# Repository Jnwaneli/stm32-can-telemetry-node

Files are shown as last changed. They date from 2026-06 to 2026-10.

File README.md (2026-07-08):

# STM32 CAN Telemetry Node - Rev A

## Overview

The STM32 CAN Telemetry Node is a custom STM32-based telemetry PCB designed in Altium Designer. The board is intended to collect analog, digital, and frequency-based sensor inputs and transmit telemetry data over a CAN bus.

Rev A includes protected 12 V input power, +5 V and +3.3 V regulation, an STM32F103C8T6 microcontroller, CAN transceiver interface, sensor input conditioning, SWD programming access, debug LEDs, test points, and mounting holes.

The hardware design is complete, routed, DRC-clean, and prepared for manufacturing. The repository also includes a starter STM32CubeMX / STM32CubeIDE firmware framework, CAN message map, bring-up documentation, and complete manufacturing outputs.

## Board Preview

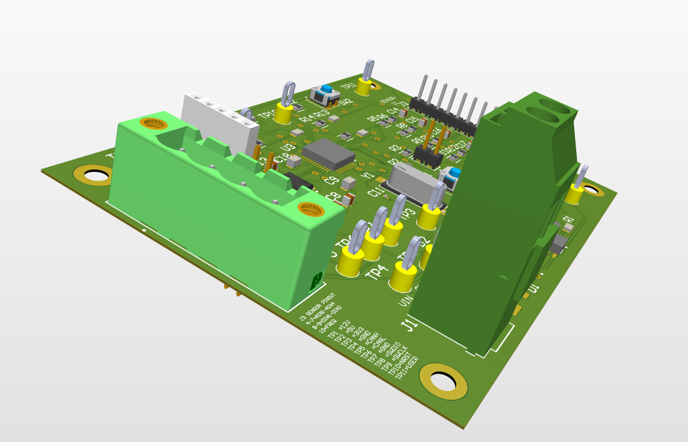
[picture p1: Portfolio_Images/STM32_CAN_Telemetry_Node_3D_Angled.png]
STM32 CAN Telemetry PCB 3D Render


**Figure 1.** 3D angled render of the STM32 CAN Telemetry Node Rev A PCB.

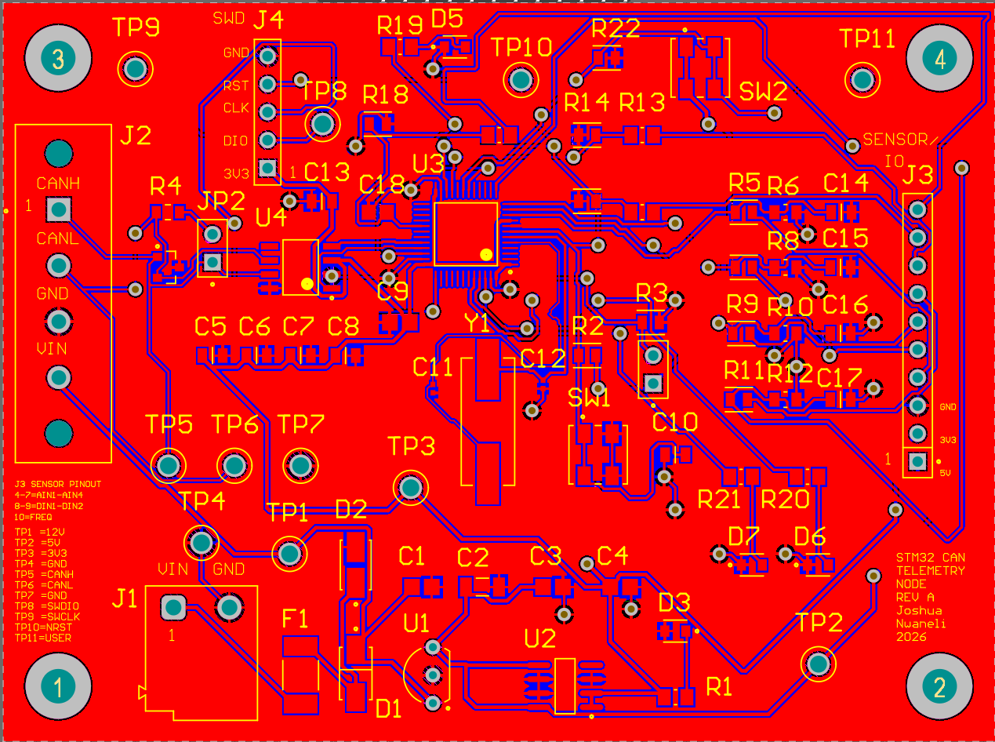
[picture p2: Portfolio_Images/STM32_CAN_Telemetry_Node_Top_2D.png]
STM32 CAN Telemetry PCB Top View


**Figure 2.** Top-side PCB layout view showing component placement, routing, connectors, mounting holes, and board labeling.

## Engineering Highlights

- Designed a custom STM32F103-based CAN telemetry PCB for vehicle sensor acquisition.
- Implemented protected 12 V input, +5 V/+3.3 V regulation, sensor inputs, CAN transceiver interface, SWD access, LEDs, and test points.
- Routed a 90 mm x 67 mm PCB and passed Altium DRC with 0 warnings, 0 rule violations, and 0 unrouted nets.
- Generated manufacturing outputs including BOM, Gerbers, drill files, pick-and-place files, and DRC report.
- Created STM32CubeMX/CubeIDE starter firmware for ADC sampling, CAN payload packing, and 100 ms CAN transmit-loop structure.

## What to Look At

- `Portfolio_Images/` - PCB renders, DRC result, STM32CubeMX configuration, and STM32CubeIDE build screenshot.
- `Manufacturing/` - Gerbers, drill files, BOM, pick-and-place files, and DRC report.
- `Docs/Design_Report.pdf` - Full hardware design explanation and design decisions.
- `Docs/CAN_Message_Map.xlsx` - Planned CAN frame structure and signal map.
- `Firmware/` - STM32CubeMX / STM32CubeIDE starter firmware.

## Project Status

- Schematic complete
- PCB layout routed
- Ground pours completed
- DRC passed with 0 warnings, 0 rule violations, and 0 unrouted nets
- Manufacturing outputs generated
- STM32CubeMX / STM32CubeIDE starter firmware created
- Firmware builds with 0 errors

## DRC Result

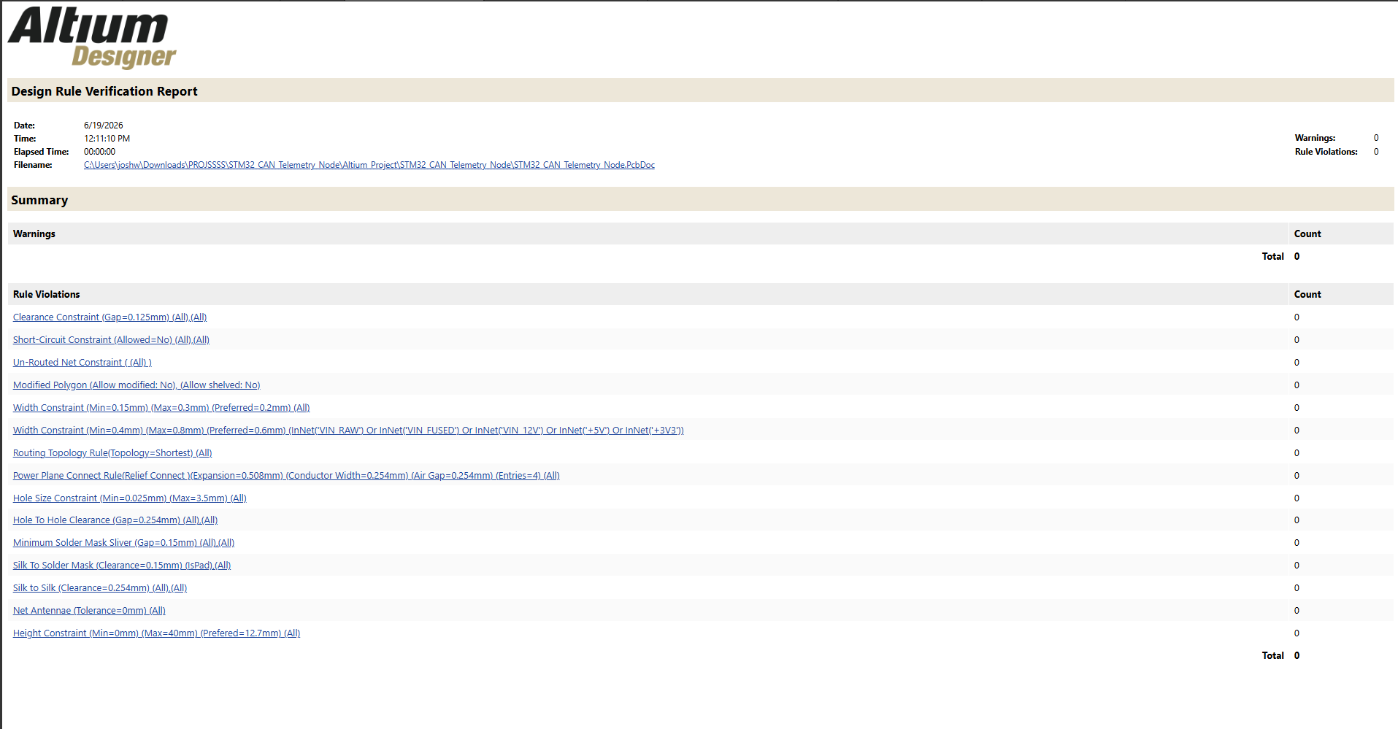
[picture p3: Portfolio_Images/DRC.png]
DRC Report


**Figure 3.** Altium Designer DRC result showing 0 warnings, 0 rule violations, and 0 unrouted nets.

## Key Features

- STM32F103C8T6 microcontroller, LQFP-48
- 12 V input through protected power path
- +5 V and +3.3 V power rails
- SN65HVD230-style 3.3 V CAN transceiver interface
- CANH/CANL connector
- Optional 120 ohm CAN termination jumper
- Four analog inputs with divider/filter networks
- Two digital inputs with pull-down networks
- One frequency/wheel-speed input
- SWD programming/debug header
- Reset and BOOT0 circuitry
- Status, CAN activity, and error LEDs
- User button
- Test points for power, CAN, SWD, reset, and user input
- 90 mm x 67 mm PCB

## System Architecture

```text
12 V Input
  -> Fuse / Protection
  -> 5 V Regulator
  -> 3.3 V Regulator
  -> STM32F103C8T6
  -> CAN Transceiver
  -> CANH / CANL Connector
```

Additional inputs:

```text
Analog Sensors -> Divider/Filter -> STM32 ADC
Digital Inputs -> Pull-down/Series Resistor -> STM32 GPIO
Frequency Input -> Filter/Pull-down -> STM32 Timer Input
SWD Header -> STM32 Programming/Debug
LEDs/Button -> Firmware Bring-up and Debug
```

## Planned CAN Message

| CAN ID | DLC | Bytes | Signal | Description |
|---|---:|---|---|---|
| 0x100 | 8 | Byte 0-1 | AIN1_RAW | Raw ADC value from AIN1 |
| 0x100 | 8 | Byte 2-3 | AIN2_RAW | Raw ADC value from AIN2 |
| 0x100 | 8 | Byte 4-5 | AIN3_RAW | Raw ADC value from AIN3 |
| 0x100 | 8 | Byte 6-7 | AIN4_RAW | Raw ADC value from AIN4 |

Planned CAN bitrate: 500 kbps  
Planned transmit period: 100 ms

## Firmware Status

A starter STM32CubeMX / STM32CubeIDE firmware framework has been added for ADC-to-CAN telemetry bring-up. The firmware configures GPIO, ADC, CAN message packing, and a 100 ms transmit loop for CAN ID `0x100`.

Current firmware status:

- STM32CubeMX configuration created for STM32F103C8T6 / STM32F103C8Tx
- SWD debug enabled
- HSE configured for the external 8 MHz crystal
- ADC1 configured for PA0-PA3 analog inputs
- CAN configured on PA11 / PA12 for planned 500 kbps operation
- CAN payload structure matches the project message map
- Starter firmware builds with 0 errors

## Firmware Configuration and Build

The starter firmware was configured in STM32CubeMX and generated for STM32CubeIDE. The project currently builds with 0 errors.

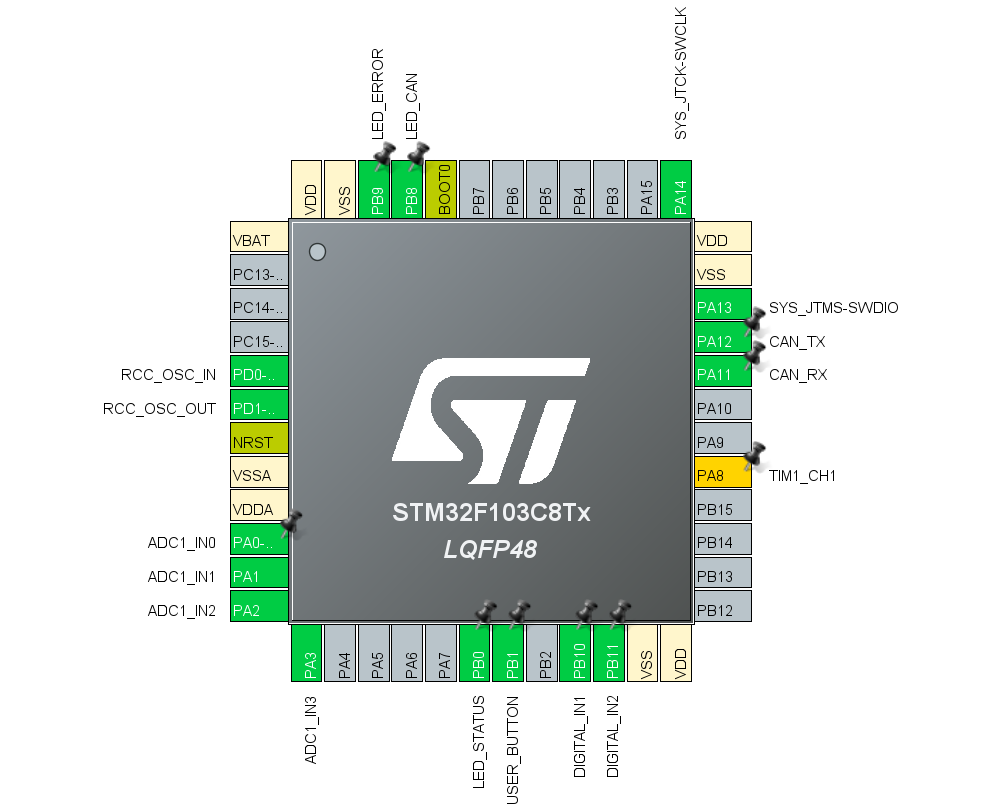
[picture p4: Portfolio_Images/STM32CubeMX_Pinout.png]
STM32CubeMX Pinout


**Figure 4.** STM32CubeMX pinout configuration showing ADC inputs, CAN pins, SWD debug pins, HSE crystal pins, GPIO LEDs, and user input signals.

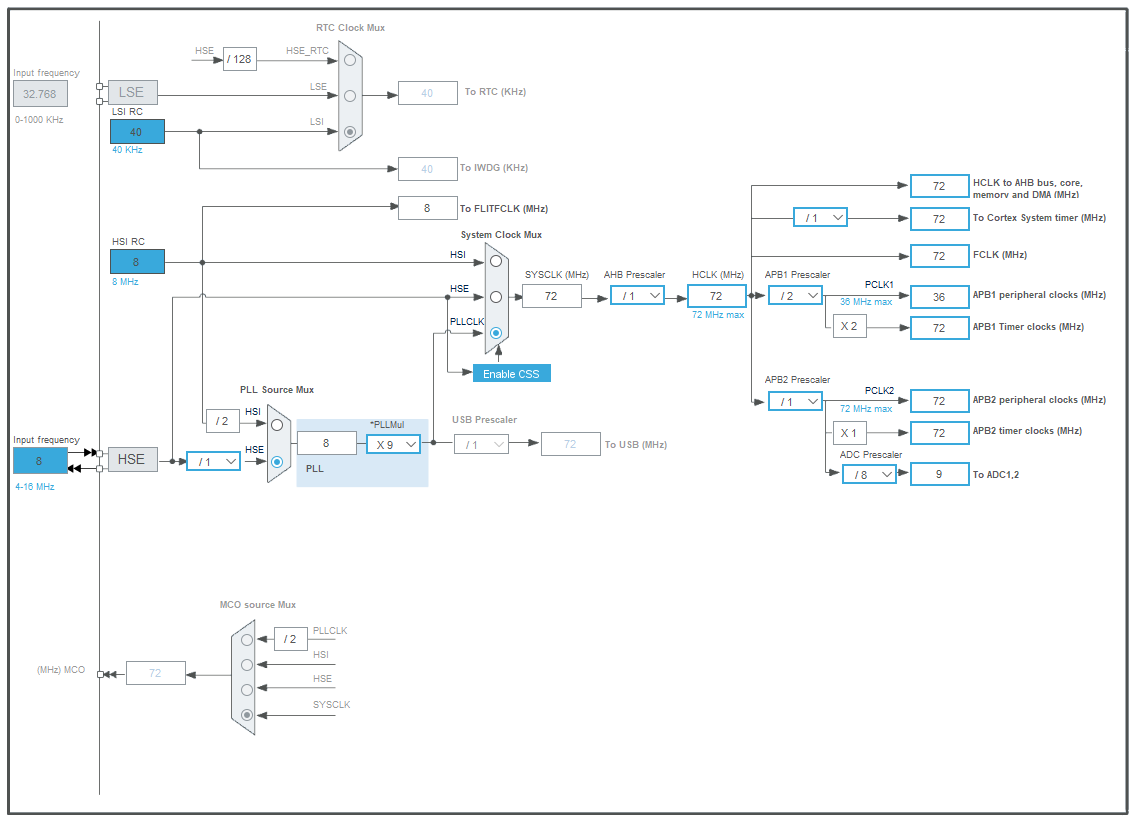
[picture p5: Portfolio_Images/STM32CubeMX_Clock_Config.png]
STM32CubeMX Clock Configuration


**Figure 5.** STM32CubeMX clock configuration using the external 8 MHz HSE crystal with PLL configuration for the STM32F103 system clock.

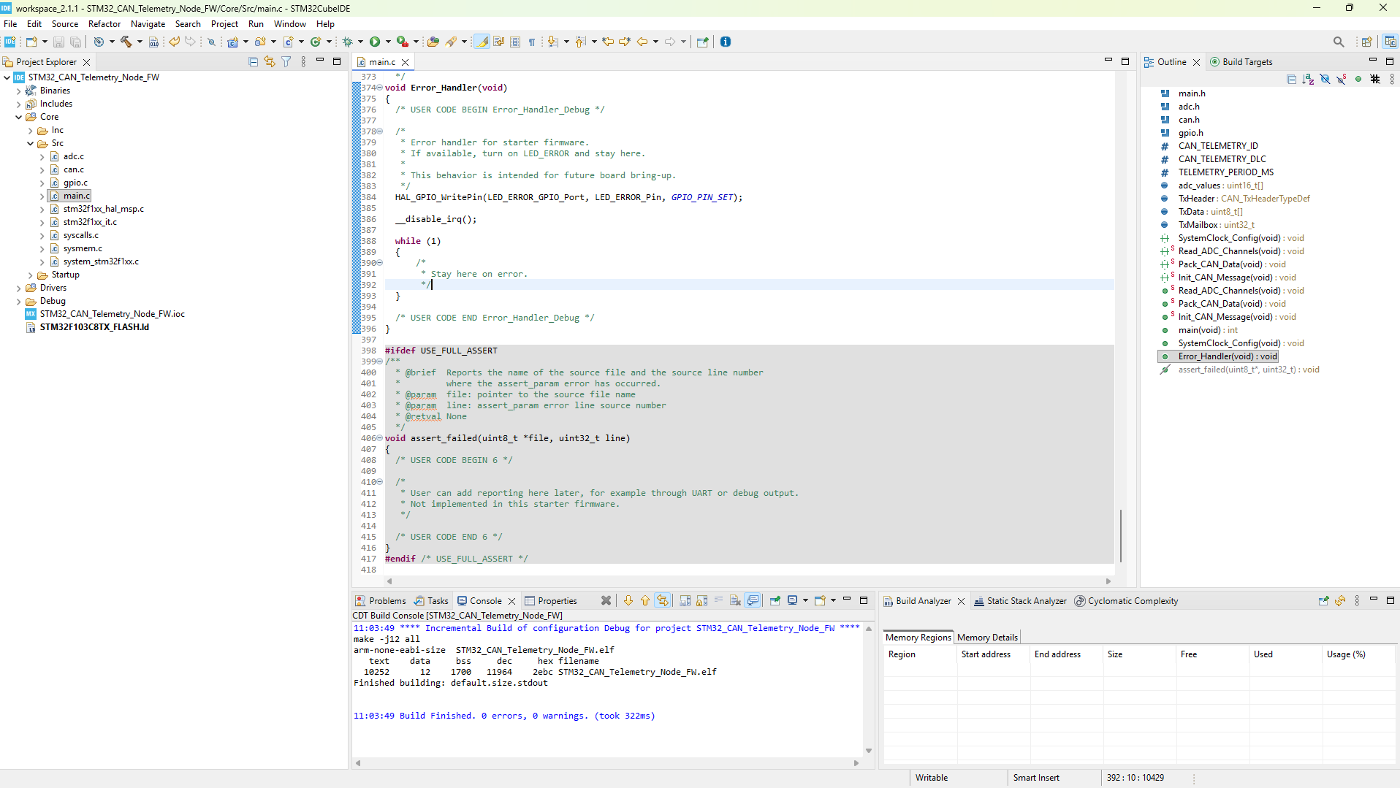
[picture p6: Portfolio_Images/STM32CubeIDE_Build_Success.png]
STM32CubeIDE Build Success


**Figure 6.** STM32CubeIDE build output showing the starter firmware project building with 0 errors.

## Project Structure

```text
STM32_CAN_Telemetry_Node/
├── Altium_Project/
├── Manufacturing/
│   ├── Gerbers/
│   ├── NC_Drill/
│   ├── BOM/
│   ├── PickPlace/
│   └── DRC/
├── Docs/
│   ├── Design_Report.pdf
│   ├── Bringup_Test_Plan.pdf
│   ├── CAN_Message_Map.xlsx
│   └── Firmware_Starter_Plan.pdf
├── Portfolio_Images/
│   ├── STM32_CAN_Telemetry_Node_3D_Angled.png
│   ├── STM32_CAN_Telemetry_Node_Top_2D.png
│   ├── DRC.png
│   ├── STM32CubeMX_Pinout.png
│   ├── STM32CubeMX_Clock_Config.png
│   └── STM32CubeIDE_Build_Success.png
├── Firmware/
│   ├── README.md
│   └── STM32_CAN_Telemetry_Node_FW/
└── README.md
```

## Documentation

Main documentation files:

- `Design_Report.pdf` - Full hardware design report
- `Bringup_Test_Plan.pdf` - Step-by-step hardware bring-up checklist
- `CAN_Message_Map.xlsx` - CAN frame and signal map
- `Firmware_Starter_Plan.pdf` - STM32 firmware bring-up approach

## Starter Firmware Main Loop

The starter firmware reads AIN1-AIN4, packs the raw ADC values into CAN frame ID `0x100`, and transmits the frame every 100 ms. Debug LEDs are included for heartbeat, CAN activity, and error indication.

Basic starter loop:

```c
while (1)
{
    Read_ADC_Channels();
    Pack_CAN_Data();

    HAL_CAN_AddTxMessage(&hcan, &TxHeader, TxData, &TxMailbox);

    HAL_GPIO_TogglePin(LED_STATUS_GPIO_Port, LED_STATUS_Pin);
    HAL_Delay(100);
}
```

## Design Scope

Rev A focuses on the core telemetry-node design package:

- Protected power input and regulated 5 V / 3.3 V rails
- STM32F103 support circuitry and SWD programming access
- ADC-based analog sensor input interfaces
- Digital and frequency input interfaces
- CAN transceiver interface and CANH/CANL connector
- Debug LEDs, user input, test points, and mounting features
- Manufacturing outputs and design documentation

## Future Rev B Improvements

- Improved automotive-grade input protection
- USB-C programming/debugging option
- SD card logging
- Enclosure or mounting bracket
- Optional second CAN channel
- More compact layout after Rev A review

## Author

Joshua Nwaneli  
June 2026

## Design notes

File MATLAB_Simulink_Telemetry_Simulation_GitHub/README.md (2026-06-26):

# MATLAB/Simulink Sensor Filtering and CAN Telemetry Simulation

## Overview

This project supports the STM32 CAN Telemetry Node Rev A by modeling the planned analog telemetry signal path before physical hardware bring-up.

The project combines a MATLAB simulation and a Simulink signal-flow model to show how four analog sensor inputs can be scaled, converted into STM32 ADC counts, filtered, and prepared for the planned CAN telemetry frame.

```text
Analog sensor input
  -> resistor-divider scaling
  -> STM32 ADC raw count
  -> filtering / signal conditioning
  -> CAN payload formatting
  -> CAN ID 0x100 telemetry frame
```

This project is part of the larger STM32 CAN Telemetry Node Rev A portfolio project.

## Project Status

This is a simulation and documentation project. It does not claim physical PCB, ADC, or CAN bus validation.

The Rev A PCB has not yet been physically assembled or tested, so these files are intended to support planned firmware bring-up and telemetry validation.

## Folder Structure

```text
MATLAB_Simulink_Telemetry_Simulation/
├── README.md
├── MATLAB/
│   └── adc_can_telemetry_simulation.m
├── Simulink/
│   ├── create_stm32_can_telemetry_model.m
│   └── stm32_can_telemetry_filter_model.slx
├── plots/
│   ├── raw_adc_counts.png
│   ├── estimated_sensor_voltages.png
│   ├── filtered_sensor_voltages.png
│   ├── example_can_payload_bytes.png
│   └── telemetry_simulation_output.csv
├── images/
│   ├── simulink_model_overview.png
│   ├── raw_adc_counts_scope.png
│   └── filtered_adc_counts_scope.png
└── docs/
    └── MATLAB_Simulink_Telemetry_Simulation_Report.pdf
```

## MATLAB Simulation

The MATLAB script is located at:

```text
MATLAB/adc_can_telemetry_simulation.m
```

It performs:

- Synthetic sensor-signal generation for four analog telemetry inputs
- STM32 12-bit ADC scaling using a 3.3 V reference
- Rev A resistor-divider modeling using 10 kOhm / 20 kOhm values
- Sensor-side voltage estimation from ADC counts
- Moving-average filtering
- CAN payload packing for standard ID `0x100`
- Plot and CSV generation

Run in MATLAB:

```matlab
cd MATLAB
adc_can_telemetry_simulation
```

Generated outputs are saved to the `plots/` folder.

## MATLAB Results

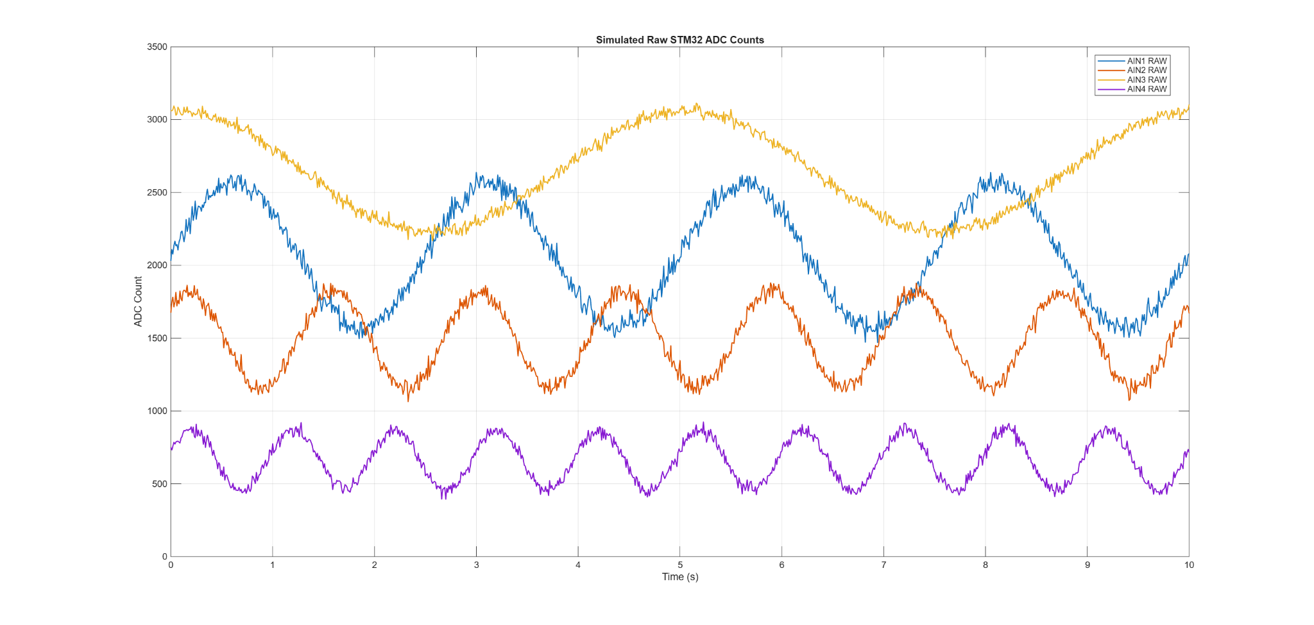
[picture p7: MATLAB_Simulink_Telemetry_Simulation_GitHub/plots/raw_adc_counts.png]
Simulated Raw STM32 ADC Counts


**Figure 1.** Simulated raw STM32 ADC counts for four analog telemetry channels.

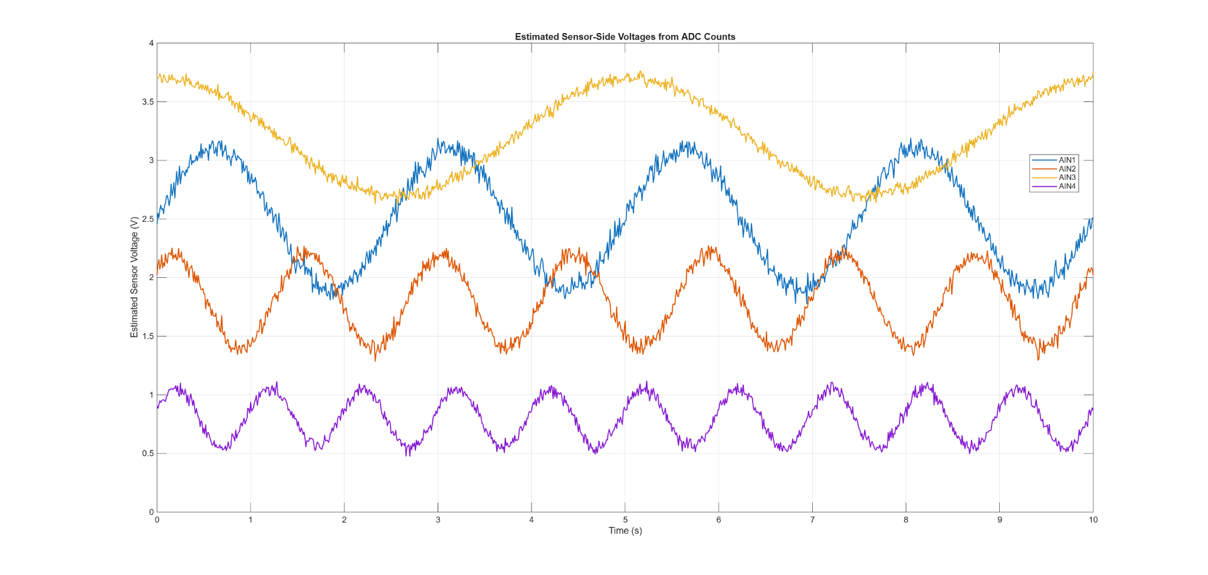
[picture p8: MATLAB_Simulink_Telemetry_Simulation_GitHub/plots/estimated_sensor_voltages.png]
Estimated Sensor-Side Voltages


**Figure 2.** Estimated sensor-side voltages reconstructed from ADC counts using the Rev A resistor-divider model.

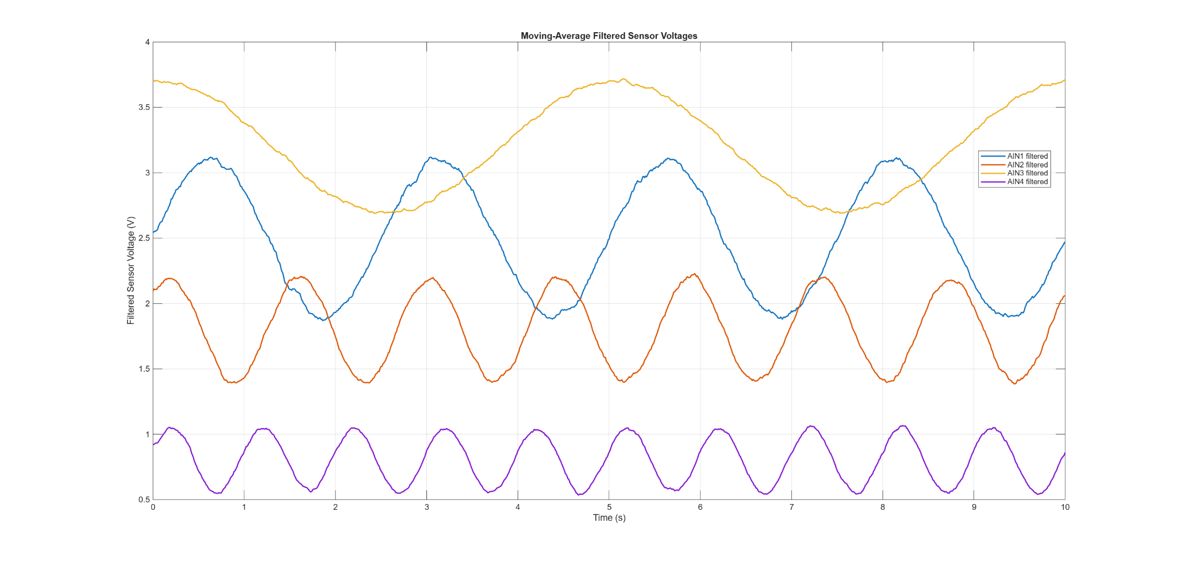
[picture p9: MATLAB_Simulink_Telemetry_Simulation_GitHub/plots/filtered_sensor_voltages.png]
Moving-Average Filtered Sensor Voltages


**Figure 3.** Moving-average filtered sensor voltage estimates for AIN1-AIN4.

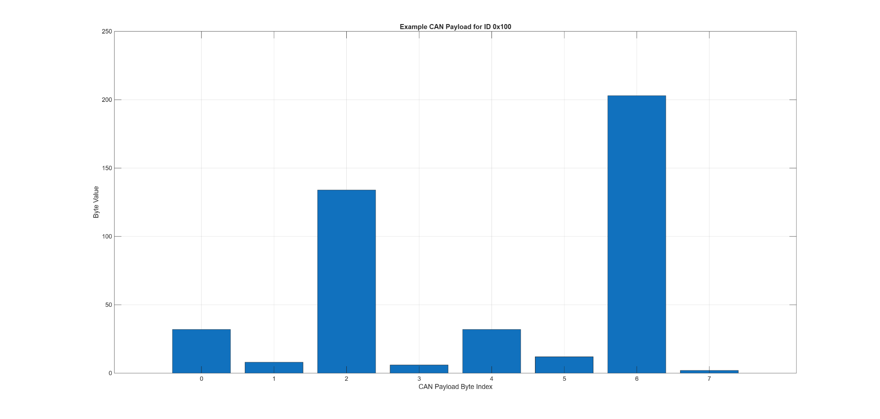
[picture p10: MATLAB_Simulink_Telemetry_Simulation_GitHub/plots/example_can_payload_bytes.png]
Example CAN Payload Bytes


**Figure 4.** Example 8-byte CAN payload for standard ID `0x100`, showing little-endian packing of four raw ADC values.

## Simulink Model

The Simulink model-generation script is located at:

```text
Simulink/create_stm32_can_telemetry_model.m
```

It creates the model:

```text
Simulink/stm32_can_telemetry_filter_model.slx
```

The Simulink model includes:

- Four simulated analog sensor input channels
- Divider scaling blocks
- ADC count conversion blocks
- First-order discrete low-pass filter blocks
- Raw ADC mux and scope
- Filtered ADC mux and scope

Run in MATLAB with Simulink installed:

```matlab
cd Simulink
create_stm32_can_telemetry_model
```

## Simulink Results

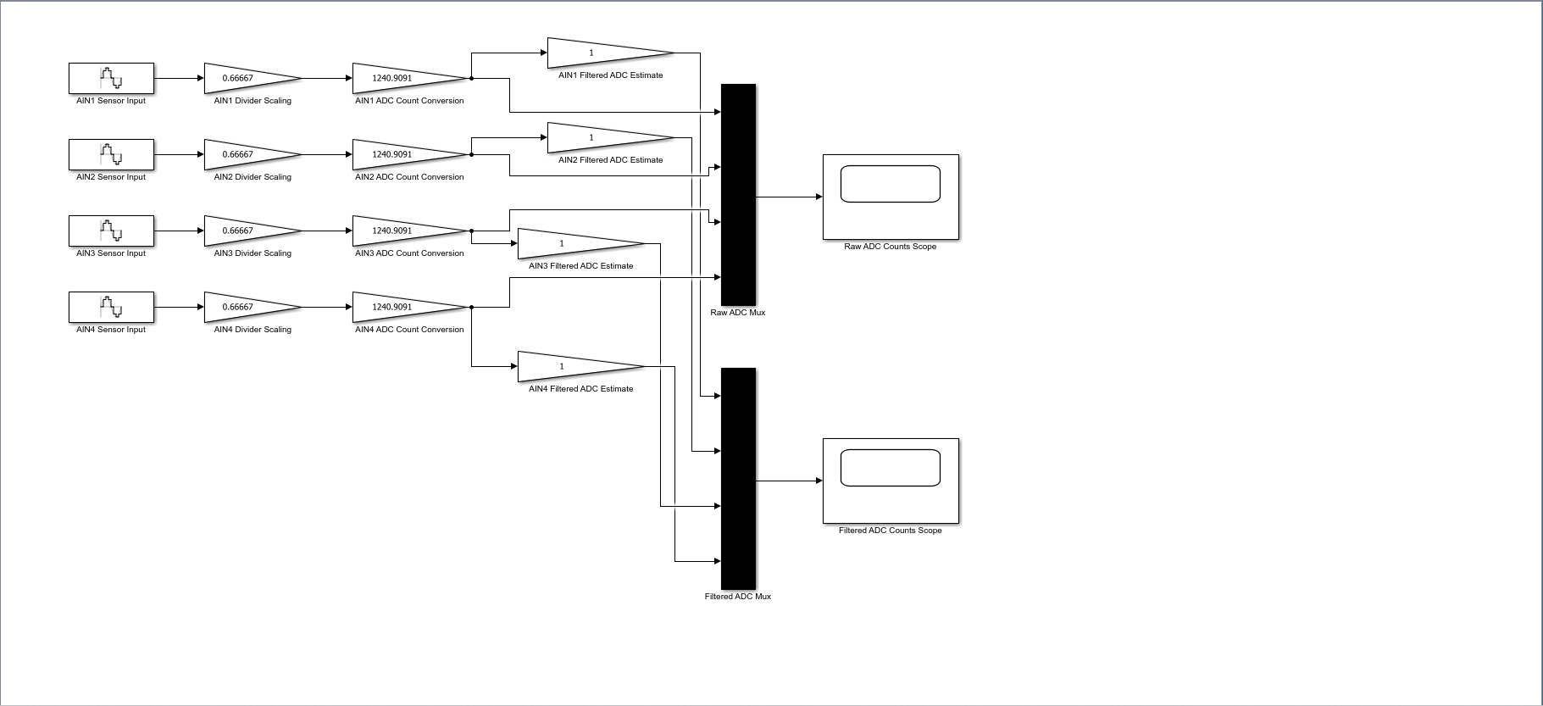
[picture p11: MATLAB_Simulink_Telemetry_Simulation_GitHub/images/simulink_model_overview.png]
Simulink Model Overview


**Figure 5.** Simulink signal-flow model showing four telemetry channels, divider scaling, ADC count conversion, discrete low-pass filtering, mux blocks, and scope outputs.

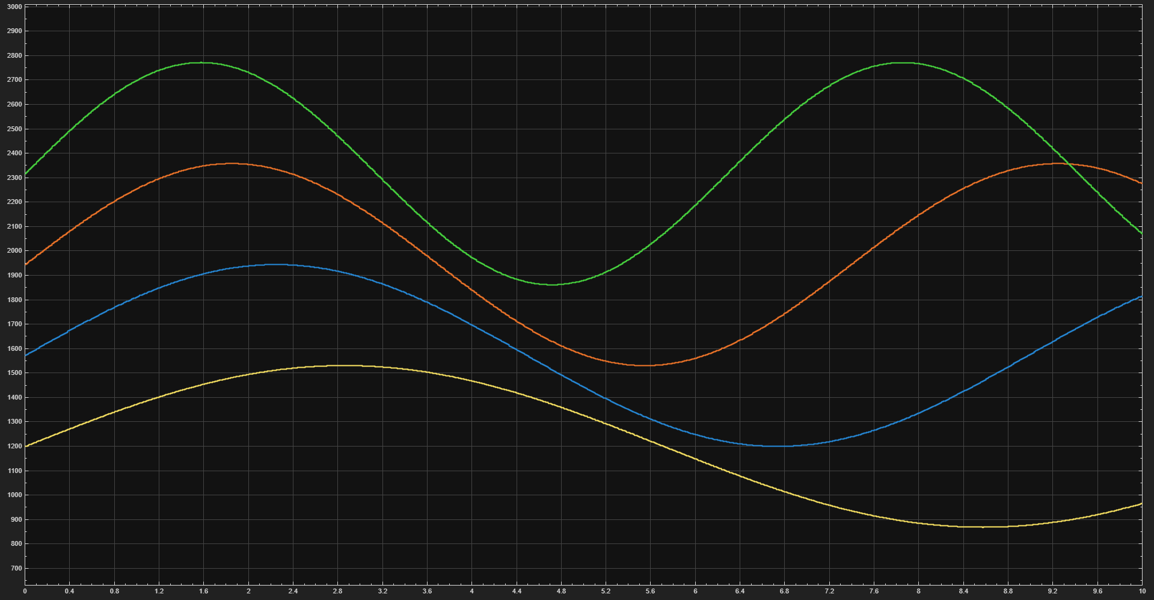
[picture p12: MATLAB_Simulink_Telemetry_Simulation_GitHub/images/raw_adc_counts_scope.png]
Raw ADC Counts Scope


**Figure 6.** Simulink raw ADC counts scope output for the four simulated telemetry channels.

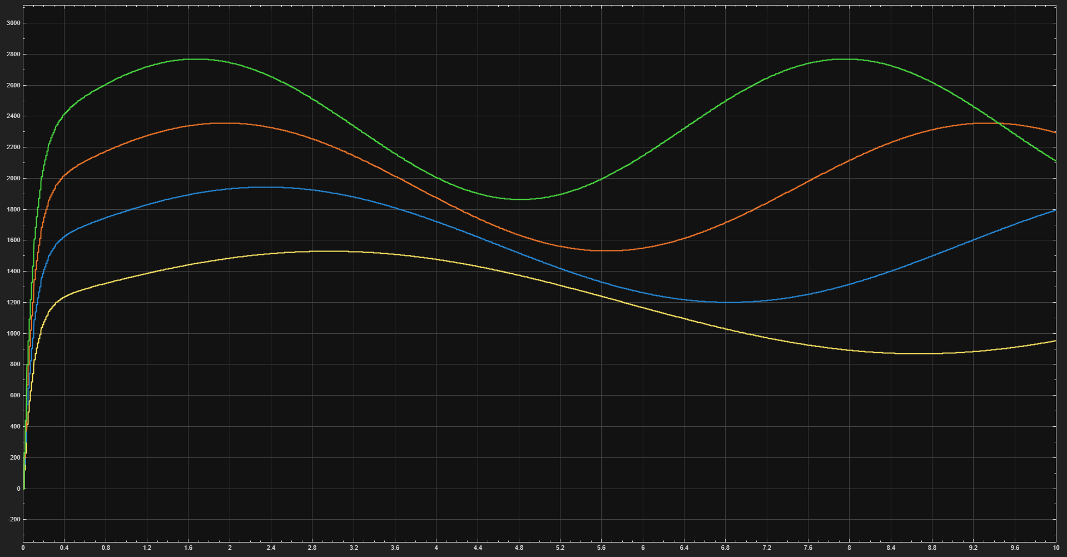
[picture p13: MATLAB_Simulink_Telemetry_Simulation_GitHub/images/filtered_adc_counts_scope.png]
Filtered ADC Counts Scope


**Figure 7.** Simulink filtered ADC counts scope output after the first-order discrete low-pass filtering stage.

## CAN Payload Format

| CAN ID | DLC | Bytes | Signal | Description |
|---|---:|---|---|---|
| 0x100 | 8 | Byte 0-1 | AIN1_RAW | Raw ADC value from AIN1 |
| 0x100 | 8 | Byte 2-3 | AIN2_RAW | Raw ADC value from AIN2 |
| 0x100 | 8 | Byte 4-5 | AIN3_RAW | Raw ADC value from AIN3 |
| 0x100 | 8 | Byte 6-7 | AIN4_RAW | Raw ADC value from AIN4 |

Each 16-bit ADC value is packed little-endian, with the low byte first and high byte second.

## Connection to STM32 Firmware

The STM32 starter firmware reads AIN1-AIN4, packs the raw ADC values into CAN frame ID `0x100`, and transmits the frame every 100 ms. This MATLAB/Simulink project models that same telemetry path at the software-simulation level before hardware validation.

## Current Limitations

- This project uses simulated sensor data.
- The plots and CSV output are not physical hardware measurements.
- ADC behavior, sensor behavior, CAN transmission, and filtering still need to be validated after Rev A PCB assembly.
- The Simulink model demonstrates the signal path and filtering concept; the embedded implementation will be refined during board bring-up.

## Resume Summary

Developed MATLAB/Simulink telemetry simulations for the STM32 CAN node, modeling ADC scaling, sensor filtering, and CAN ID `0x100` payload formatting before hardware bring-up.

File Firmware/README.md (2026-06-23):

# Firmware — STM32 CAN Telemetry Node Rev A

## Status

A starter STM32CubeMX / STM32CubeIDE firmware framework has been created for the STM32 CAN Telemetry Node Rev A board.

Current firmware status:

- STM32CubeMX configuration created for STM32F103C8T6 / STM32F103C8Tx
- STM32CubeIDE starter firmware generated
- SWD debug enabled
- HSE configured for the external 8 MHz crystal
- ADC1 configured for AIN1-AIN4 on PA0-PA3
- CAN configured on PA11 / PA12 for planned 500 kbps operation
- CAN frame structure implemented for telemetry ID `0x100`
- Starter firmware builds with 0 errors

This firmware has not yet been tested on physical Rev A hardware. Hardware validation is planned after PCB assembly.

## Target Hardware

- MCU: STM32F103C8T6, LQFP-48
- Programming/debug interface: SWD through J4
- SWDIO: PA13
- SWCLK: PA14
- External clock: 8 MHz HSE crystal
- CAN transceiver: SN65HVD230-style 3.3 V CAN transceiver
- Planned CAN bitrate: 500 kbps
- Planned telemetry transmit period: 100 ms
- Main CAN message ID: `0x100`

## Configured Pin Mapping

| Signal | STM32 Pin | Function |
|---|---|---|
| AIN1 | PA0 | ADC1_IN0 |
| AIN2 | PA1 | ADC1_IN1 |
| AIN3 | PA2 | ADC1_IN2 |
| AIN4 | PA3 | ADC1_IN3 |
| FREQ_IN | PA8 | TIM1_CH1 / planned frequency input |
| CAN_RX | PA11 | CAN receive |
| CAN_TX | PA12 | CAN transmit |
| SWDIO | PA13 | SWD debug |
| SWCLK | PA14 | SWD debug |
| OSC_IN | PD0 | HSE input |
| OSC_OUT | PD1 | HSE output |

## Implemented Starter Firmware Features

The current starter firmware includes:

- System clock initialization using the external 8 MHz HSE crystal
- GPIO initialization for debug LEDs and user input signals
- ADC setup for four analog telemetry inputs
- ADC calibration before first conversion
- CAN transmit header setup for standard ID `0x100`
- Packing of four raw 16-bit ADC readings into an 8-byte CAN payload
- 100 ms transmit-loop structure
- Status LED heartbeat behavior
- CAN activity LED toggle when a CAN message is queued
- Error LED behavior for CAN or ADC initialization issues

## CAN Message

| CAN ID | DLC | Bytes | Signal | Description |
|---|---:|---|---|---|
| 0x100 | 8 | Byte 0-1 | AIN1_RAW | Raw ADC value from AIN1 |
| 0x100 | 8 | Byte 2-3 | AIN2_RAW | Raw ADC value from AIN2 |
| 0x100 | 8 | Byte 4-5 | AIN3_RAW | Raw ADC value from AIN3 |
| 0x100 | 8 | Byte 6-7 | AIN4_RAW | Raw ADC value from AIN4 |

Payload format is little-endian for each 16-bit ADC value:

```text
Byte 0 = AIN1 low byte
Byte 1 = AIN1 high byte
Byte 2 = AIN2 low byte
Byte 3 = AIN2 high byte
Byte 4 = AIN3 low byte
Byte 5 = AIN3 high byte
Byte 6 = AIN4 low byte
Byte 7 = AIN4 high byte
```

## Main Loop Structure

```c
while (1)
{
    Read_ADC_Channels();
    Pack_CAN_Data();

    if (HAL_CAN_AddTxMessage(&hcan, &TxHeader, TxData, &TxMailbox) == HAL_OK)
    {
        HAL_GPIO_TogglePin(LED_CAN_GPIO_Port, LED_CAN_Pin);
    }
    else
    {
        HAL_GPIO_WritePin(LED_ERROR_GPIO_Port, LED_ERROR_Pin, GPIO_PIN_SET);
    }

    HAL_GPIO_TogglePin(LED_STATUS_GPIO_Port, LED_STATUS_Pin);

    HAL_Delay(100);
}
```

## Project Files

The firmware folder contains the STM32CubeMX / STM32CubeIDE starter firmware files.

Expected folder structure:

```text
Firmware/
├── README.md
└── STM32_CAN_Telemetry_Node_FW/
    ├── Core/
    ├── Drivers/
    └── STM32_CAN_Telemetry_Node_FW.ioc
```

Depending on upload method, hidden STM32CubeIDE/Eclipse project files such as `.project`, `.cproject`, or `.settings/` may not be present in GitHub. The `.ioc` file preserves the CubeMX peripheral configuration and can be used to regenerate the project if needed.

## Current Limitations

Because the Rev A PCB has not been assembled yet, the following items are still planned:

- Flashing firmware to physical hardware
- Verifying 3.3 V and 5 V rails before programming
- Confirming SWD connection
- Testing LED behavior
- Measuring ADC readings from real sensor inputs
- Verifying CAN transmission with a CAN analyzer
- Validating CAN bitrate and bus termination
- Testing error handling during board bring-up
- Implementing and validating frequency input capture for FREQ_IN
- Reading and reporting DIN1 and DIN2 digital input states

## Future Firmware Improvements

- Convert raw ADC counts into calibrated sensor values
- Add digital input reporting for DIN1 and DIN2
- Add timer input capture for FREQ_IN / wheel-speed signal
- Add CAN receive support for configuration commands
- Add timeout/error flags
- Add diagnostic CAN messages
- Add configurable transmit rate
- Add structured firmware documentation
- Add hardware-tested bring-up notes after Rev A assembly

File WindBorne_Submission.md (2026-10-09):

# WindBorne Electrical Engineer Intern — PCB Submission

## STM32 CAN Telemetry Node

I designed this STM32F103-based telemetry PCB in Altium Designer to acquire vehicle sensor data and transmit it over a CAN bus.

The board includes:

- Protected 12 V input power
- 5 V and 3.3 V regulation
- STM32F103C8T6 microcontroller
- CAN transceiver interface
- Four analog sensor inputs
- Digital and frequency inputs
- SWD programming/debug access
- Status, CAN activity, and error LEDs
- Test points for power, CAN, reset, and debugging

The PCB layout is complete, passes Altium DRC with 0 rule violations and 0 unrouted nets, and includes manufacturing outputs such as Gerbers, drill files, BOM, and pick-and-place files.

## A Design Feature I Like

One small feature I particularly like is the selectable 120-ohm CAN termination.

The termination resistor can be enabled with a jumper when the telemetry node is located at the end of the CAN bus, or disabled when the board is used elsewhere on the network.

This allows the same PCB to support multiple physical positions on the CAN network without modifying or redesigning the board.

## PCB

3D PCB Render

## PCB Layout

Top PCB Layout

## Schematic

[View Full Schematic](Portfolio_Images/STM32_CAN_Telemetry_Node_Schematic.PDF)

## Design Rule Check

Altium DRC

The complete project, including Altium design files, manufacturing outputs, firmware starter code, CAN message map, and bring-up documentation, is available in this repository.

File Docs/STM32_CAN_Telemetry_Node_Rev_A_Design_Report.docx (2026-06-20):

STM32 CAN Telemetry Node

Rev A — Design Report

Author | Joshua Nwaneli
Date | June 2026
Design Tool | Altium Designer
PCB Size | 90 mm × 67 mm
MCU | STM32F103C8T6, LQFP-48
CAN Bitrate (planned) | 500 kbps
DRC Status | 0 warnings · 0 rule violations · 0 unrouted nets
Design Status | Schematic complete · PCB routed · DRC clean · Bring-up planned

Completed in Altium Designer. Physical assembly and firmware bring-up planned as next steps.

# 1. Project Overview

The STM32 CAN Telemetry Node is a purpose-built PCB designed to collect vehicle sensor data and transmit it over a CAN bus. The board accepts a 12 V vehicle input, regulates it through a two-stage power chain to +5 V and +3.3 V, and uses an STM32F103C8T6 microcontroller to sample analog, digital, and frequency signals before encoding them into CAN frames. This design was created as a portfolio project and embedded hardware design demonstration, completed in Altium Designer.

Rev A covers full schematic capture across six sheets, a routed and DRC-clean PCB layout, a Bill of Materials, and a complete manufacturing output package. Physical assembly and firmware bring-up are planned as the next phase. The intended application is an automotive or motorsport environment where a CAN network aggregates data from distributed sensor nodes.

# 2. Design Goals

- Accept a 12 V vehicle input with fuse and transient protection.
- Generate regulated +5 V and +3.3 V rails from the 12 V input.
- Interface an STM32F103C8T6 with a CAN transceiver for 500 kbps CAN communication.
- Condition four analog voltage inputs, two digital inputs, and one frequency/wheel-speed input.
- Transmit CAN message ID 0x100 at a 100 ms interval, encoding four 16-bit raw ADC values.
- Include debug infrastructure: SWD programming header, status LEDs, user button, and labeled test points.
- Pass Altium DRC with 0 warnings and 0 rule violations before releasing manufacturing outputs.

# 3. System Block Diagram

Figure 1 shows the top-level block diagram, drawn as schematic sheet 00 in Altium. It traces the power path from the 12 V input through fuse and protection circuitry, 5 V regulation, and 3.3 V regulation down to the STM32 MCU. From the MCU, the diagram shows the signal paths to each subsystem: ADC inputs from analog sensors, GPIO connections for digital inputs and status LEDs, a timer input for the wheel-speed/frequency signal, the SWD debug interface, and the CAN_TX/CAN_RX path through the transceiver to the CAN connector.

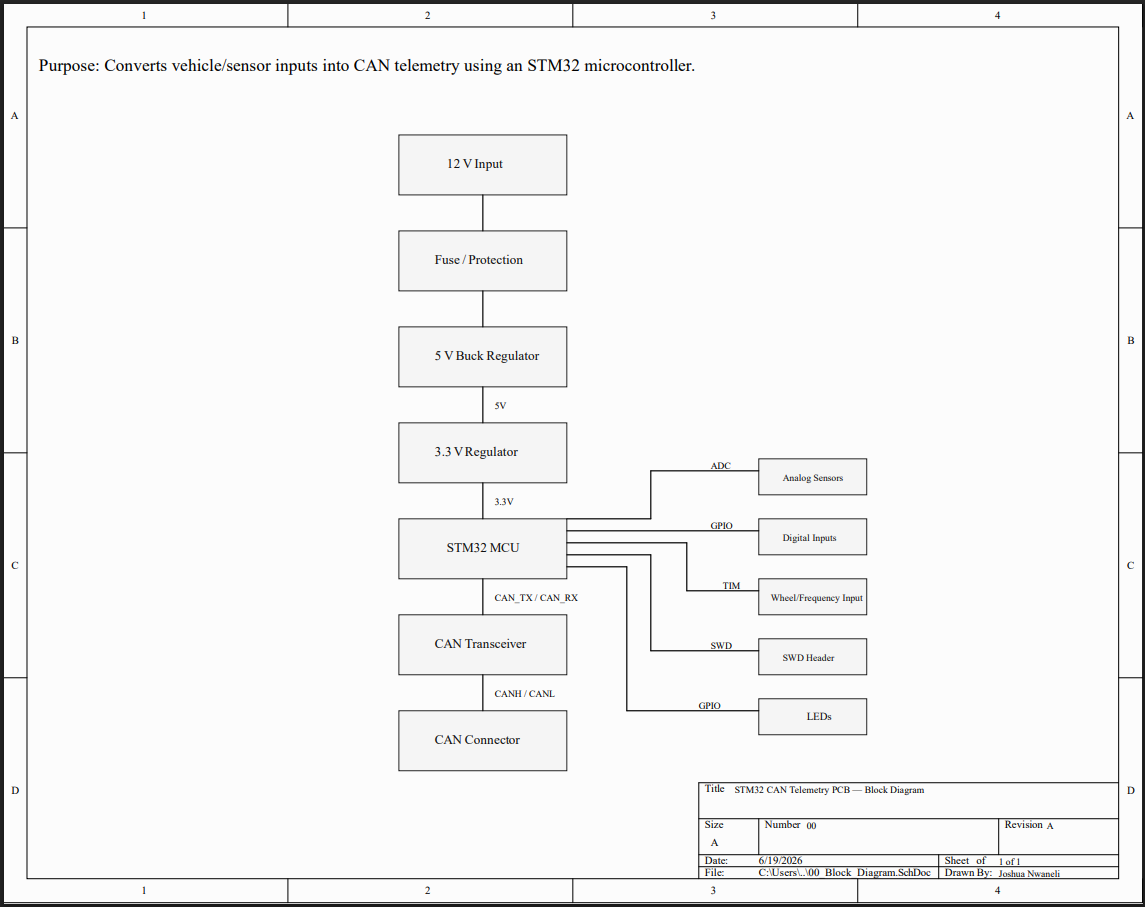
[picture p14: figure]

Figure 1: System Block Diagram

# 4. Power Architecture

The power supply chain, shown in Figure 2, starts at J1, a 2-pin power input connector that accepts the raw 12 V vehicle supply. The input path includes a resettable fuse (F1) and a reverse-polarity protection diode (D1), followed by an input TVS diode (D2) across the rail for transient suppression. This combination is intended to protect the board against overcurrent events, reverse connection, and voltage transients common in automotive environments.

From the protected 12 V rail (VIN_12V), a 5 V switching regulator (U1) steps the voltage down to +5 V. The +5 V rail then feeds a 3.3 V LDO regulator (U2) that produces the supply used by the STM32 and CAN transceiver. A design note on the schematic explicitly states that the STM32 VDD must not be driven directly from +5 V. Bulk and bypass capacitors are placed at each stage to stabilize the rails under load. A power-indicator LED (D3) with a series current-limiting resistor confirms +3.3 V rail presence. Test points TP1 through TP4 provide probe access to VIN_12V, +5 V, +3.3 V, and GND during bring-up.

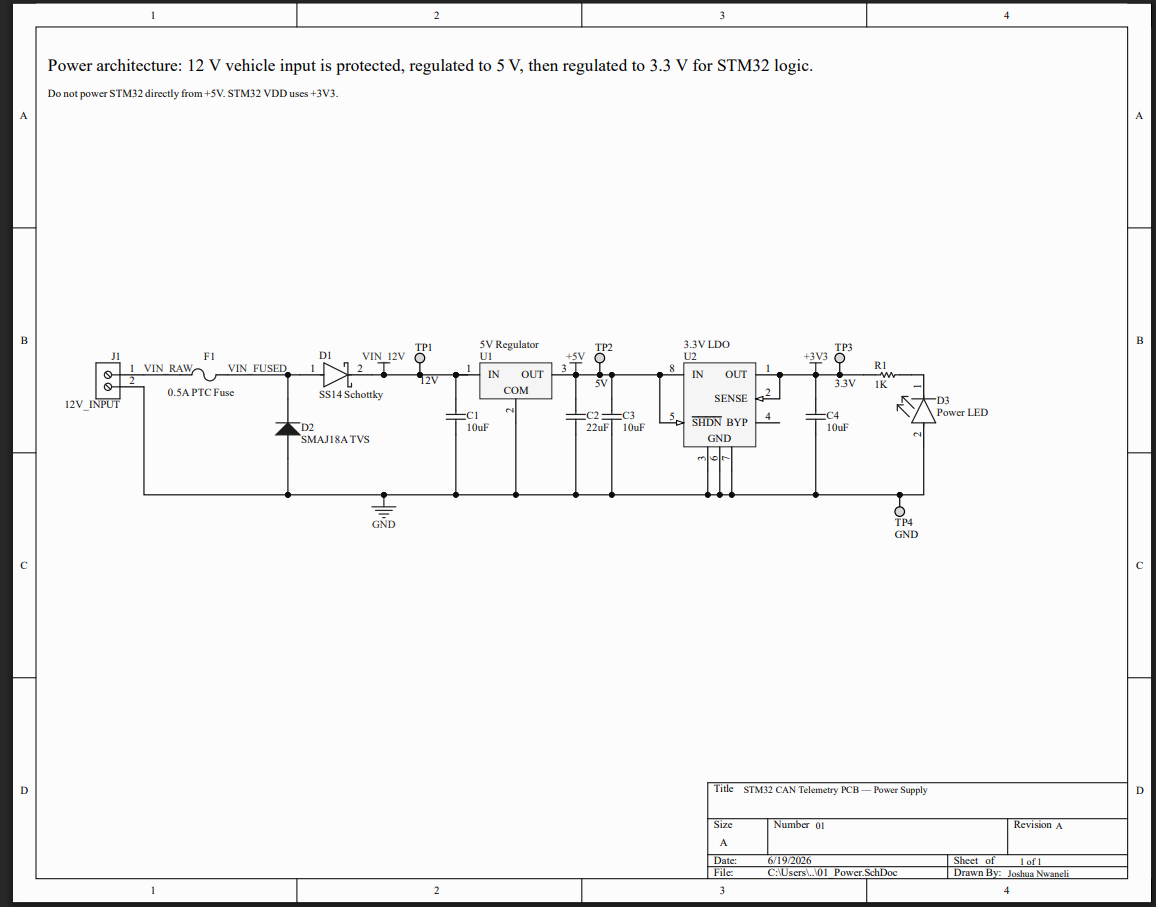
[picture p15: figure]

Figure 2: Power Architecture Schematic

# 5. STM32 Microcontroller Section

The central controller is the STM32F103C8T6, an ARM Cortex-M3 device in a 48-pin LQFP package with 64 KB Flash and 20 KB SRAM. The STM32 symbol is divided into U3A and U3B sections, with U3A showing the I/O pins and U3B showing the power pins. The MCU is powered entirely from the +3.3 V rail.

Multiple 0.1 µF ceramic decoupling capacitors (C5–C8) are placed directly at each VDD pin, and a 10 µF bulk capacitor (C9) supports the local power area. An external 8 MHz crystal oscillator (Y1) with 27 pF load capacitors (C11, C12) provides the clock source, improving frequency accuracy and CAN bit-timing stability over the internal RC oscillator.

The reset circuit uses a pull-up resistor on NRST, a decoupling capacitor, and a normally-open pushbutton (SW1) that pulls NRST low when pressed. BOOT0 is pulled down through a resistor for normal flash boot operation, with a 2-pin header (JP1) that allows BOOT0 to be pulled high to enter the STM32 system bootloader. Net labels on the MCU schematic connect each peripheral signal to its respective sub-schematic: CAN_TX and CAN_RX to the CAN sheet, ADC_IN0–ADC_IN3 and FREQ_TIMER_IN to the sensor sheet, and LED_STATUS, LED_CAN, LED_ERROR, USER_BUTTON, SWDIO, SWCLK, and NRST to the debug/SWD sheet.

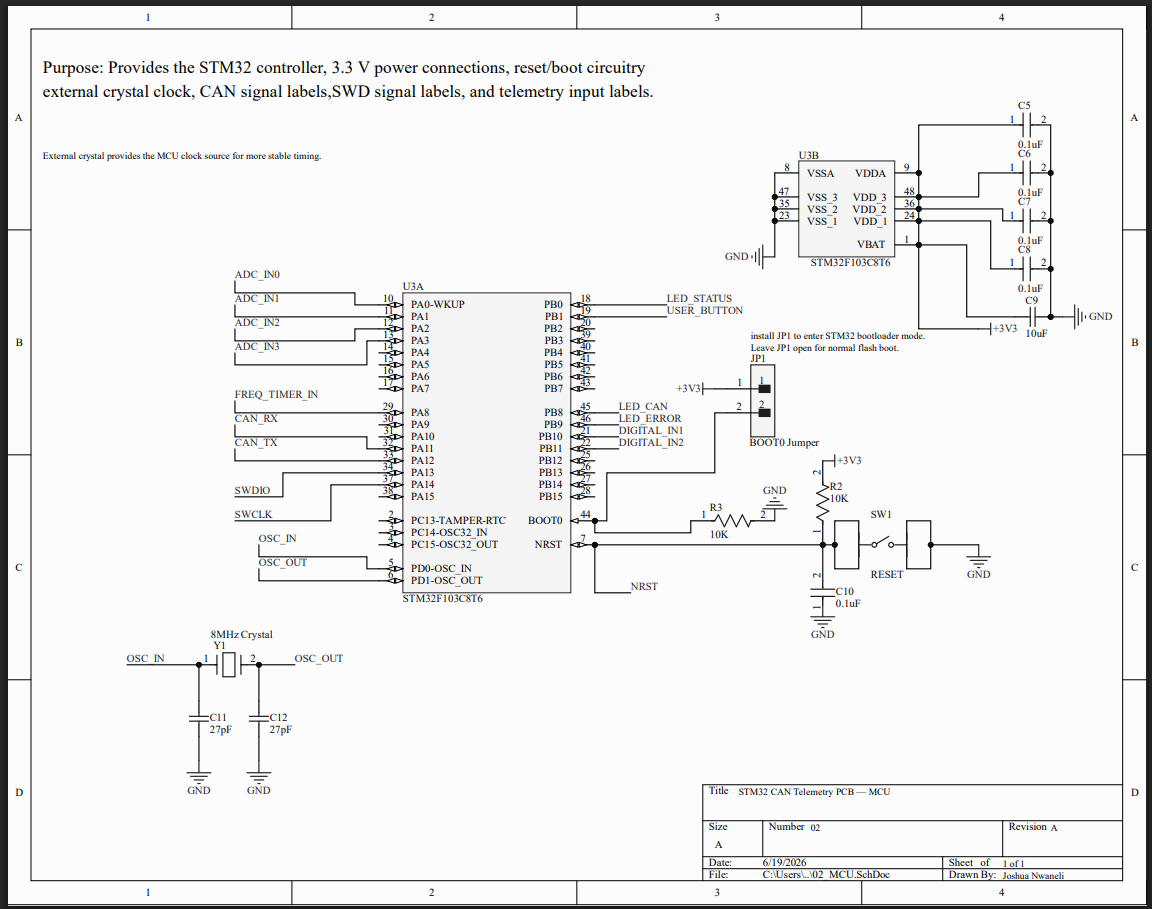
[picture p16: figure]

Figure 3: STM32 MCU Schematic

# 6. CAN Interface

The CAN interface schematic (Figure 4) converts STM32 logic-level CAN_TX/CAN_RX signals into differential CANH/CANL bus signals as required by ISO 11898. A 3.3 V CAN transceiver (U4) interfaces the STM32 to the differential bus. CANH and CANL connect externally through J2, a 4-pin CAN bus connector that also carries GND and VIN_12V. A CAN TVS diode (D4) is placed across CANH and CANL near the connector to clamp transient events before they reach the transceiver. Test points TP5–TP7 provide probe access to CANH, CANL, and GND during bus bring-up.

An optional 120 Ω termination resistor (R4) can be enabled by installing jumper JP2. A schematic note specifies that R4 should only be installed when the board is at the physical end of the CAN bus. The planned bitrate is 500 kbps with a 100 ms transmit interval.

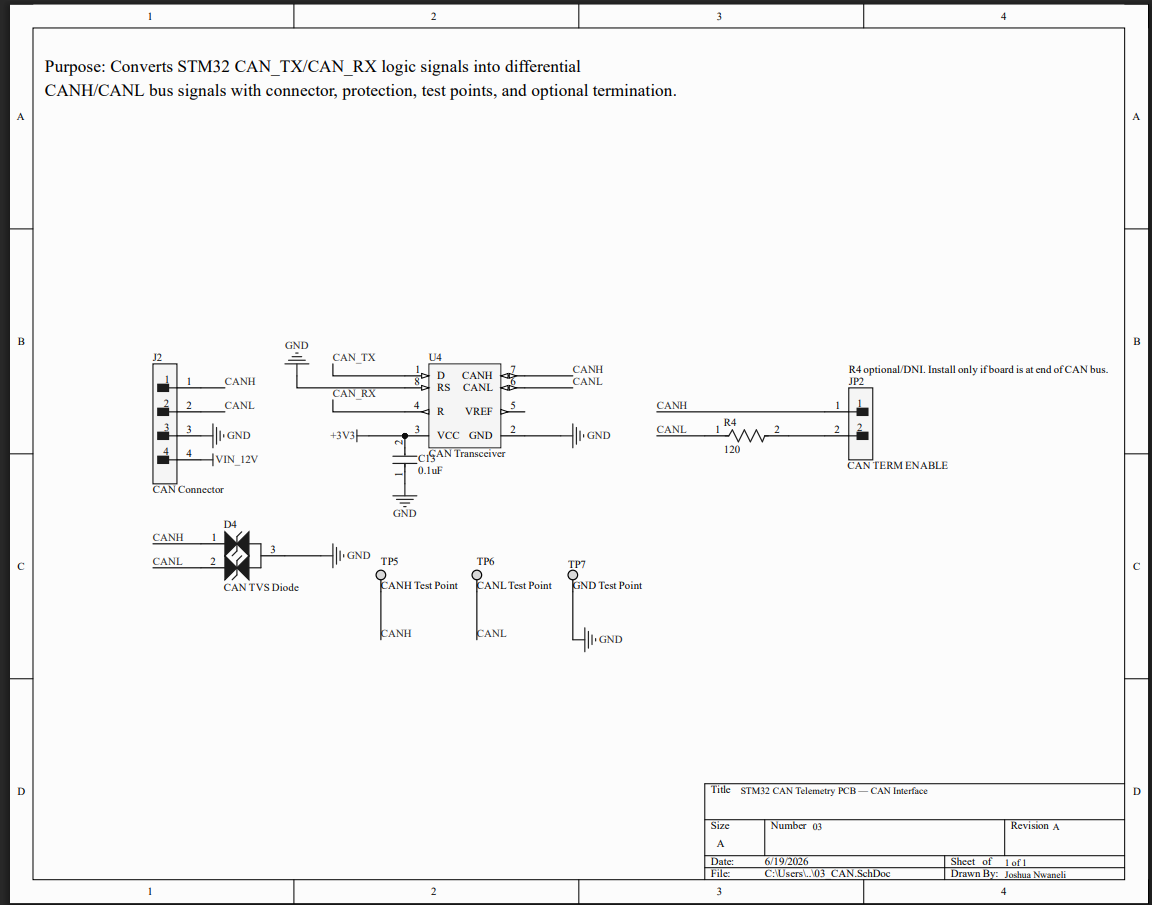
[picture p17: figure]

Figure 4: CAN Interface Schematic

Table 1: CAN Message Map (ID 0x100 · 500 kbps · 100 ms period)

CAN ID | DLC | Bytes | Signal | Description
0x100 | 8 | Byte 0–1 | AIN1_RAW | Raw ADC value from AIN1
0x100 | 8 | Byte 2–3 | AIN2_RAW | Raw ADC value from AIN2
0x100 | 8 | Byte 4–5 | AIN3_RAW | Raw ADC value from AIN3
0x100 | 8 | Byte 6–7 | AIN4_RAW | Raw ADC value from AIN4

# 7. Sensor Input Circuits

The sensor input schematic (Figure 5) covers all signal conditioning between the external sensor connector J3 and the STM32 ADC and GPIO pins. J3 is a multi-pin sensor header carrying +5 V, +3.3 V, GND, four analog inputs, two digital inputs, and one frequency/wheel-speed input.

Each of the four analog inputs (AIN1–AIN4) uses a 10 kΩ/20 kΩ resistor divider designed to scale a 0–5 V sensor range down to 0–3.3 V for the STM32 12-bit ADC, with a 100 nF filter capacitor at the ADC input. The two digital inputs (DIN1, DIN2) each use a 1 kΩ series resistor and a 10 kΩ pull-down. The frequency input (FREQ_IN) uses the same 1 kΩ/10 kΩ network with an additional 1 nF capacitor to filter noise while preserving the pulse edge for timer capture. Table 2 summarizes signal routing and circuit configuration for all seven inputs.

Table 2: Sensor Input Signal Map

Signal | Connector Net | MCU Net | Circuit | Notes
AIN1 | AIN1 | ADC_IN0 | 10 kΩ/20 kΩ divider + 100 nF | Scales 0–5 V to 0–3.3 V
AIN2 | AIN2 | ADC_IN1 | 10 kΩ/20 kΩ divider + 100 nF | Scales 0–5 V to 0–3.3 V
AIN3 | AIN3 | ADC_IN2 | 10 kΩ/20 kΩ divider + 100 nF | Scales 0–5 V to 0–3.3 V
AIN4 | AIN4 | ADC_IN3 | 10 kΩ/20 kΩ divider + 100 nF | Scales 0–5 V to 0–3.3 V
DIN1 | DIN1 | DIGITAL_IN1 | 1 kΩ series + 10 kΩ pull-down | Logic level input
DIN2 | DIN2 | DIGITAL_IN2 | 1 kΩ series + 10 kΩ pull-down | Logic level input
FREQ | FREQ_IN | FREQ_TIMER_IN | 1 kΩ + 10 kΩ pull-down + 1 nF | Timer capture, wheel speed

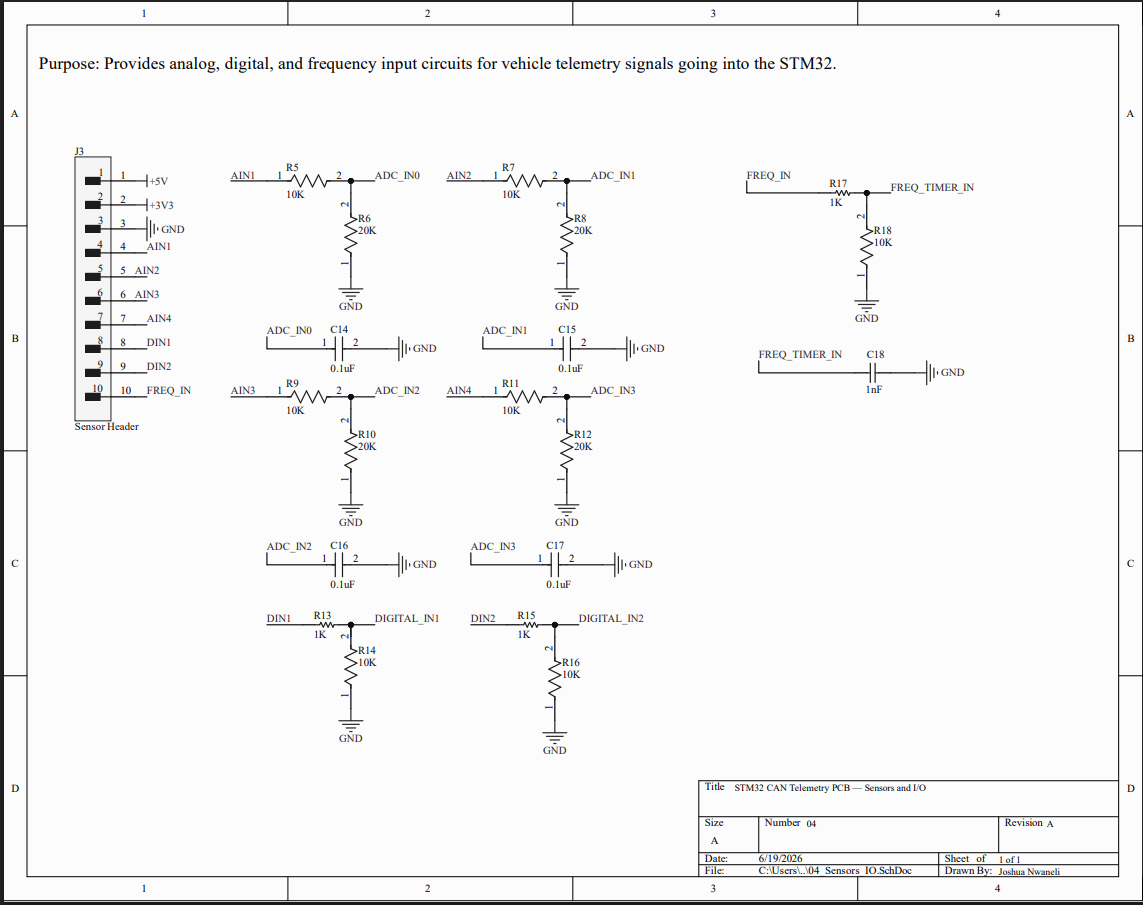
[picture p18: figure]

Figure 5: Sensor/Input Schematic

# 8. Debug and Programming Interface

The debug schematic (Figure 6) consolidates board bring-up features onto a single sheet. J4 is a 5-pin SWD programming header that exposes +3.3 V, SWDIO, SWCLK, NRST, and GND, allowing a standard ST-Link programmer to be connected for firmware flashing and debugging. Test points TP8–TP11 provide probe access to SWDIO, SWCLK, NRST, and USER_BUTTON without needing to probe the connector pins directly.

Three status LEDs indicate runtime state: D5 (LED_STATUS) reflects general firmware activity, D6 (LED_CAN) indicates CAN bus transmission, and D7 (LED_ERROR) signals fault conditions. Each LED is driven through a 1 kΩ current-limiting resistor from an STM32 GPIO pin. A user pushbutton (SW2) connected to USER_BUTTON with a pull-down resistor provides firmware-controlled input for testing.

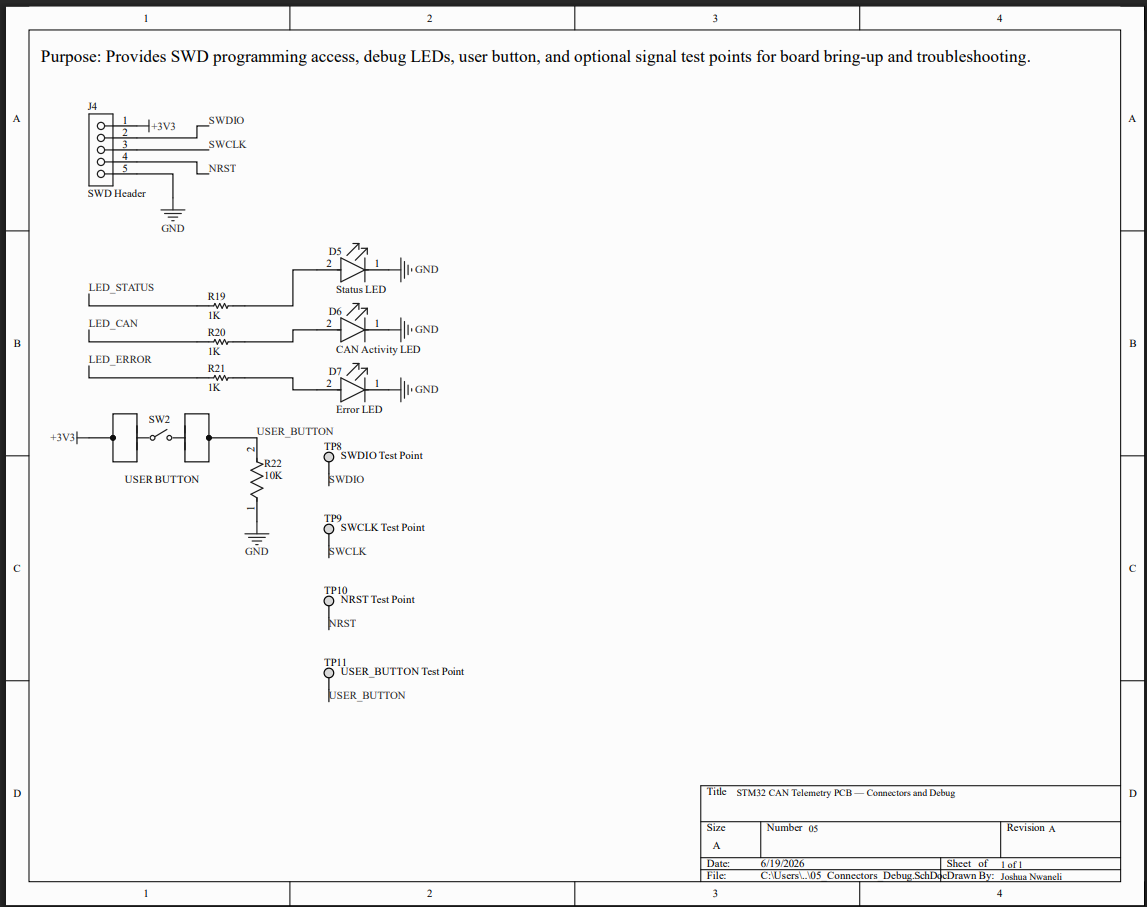
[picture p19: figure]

Figure 6: Debug and SWD Schematic

# 9. PCB Layout Decisions

The final PCB measures 90 mm × 67 mm, routed entirely in Altium Designer. Mounting holes near the four corners allow the board to be secured in an enclosure or chassis bracket. Ground pours on both copper layers reduce return path impedance and simplify GND connectivity across the board.

An early placement iteration positioned the STM32 near the left edge, close to the CAN connector. Pin escape routing from the LQFP-48 package proved difficult given the simultaneous demands of CAN, ADC, crystal, SWD, and power traces. Moving the MCU to the board center resulted in cleaner routing to each subsystem. The final zone arrangement is:

- Power (J1, F1, D1, D2, U1, U2, D3) — lower-left, keeping the switching regulator away from ADC traces.
- STM32 (U3, Y1, reset and boot circuitry, decoupling) — board center.
- CAN interface (U4, J2, D4, JP2, CAN test points) — left side, adjacent to the CAN connector.
- Sensor inputs (J3, divider and filter networks R5–R18, C14–C18) — right side.
- SWD and debug (J4, LEDs, SW2, debug test points) — top edge, accessible from the board perimeter.


Figure 7: Final PCB Top View

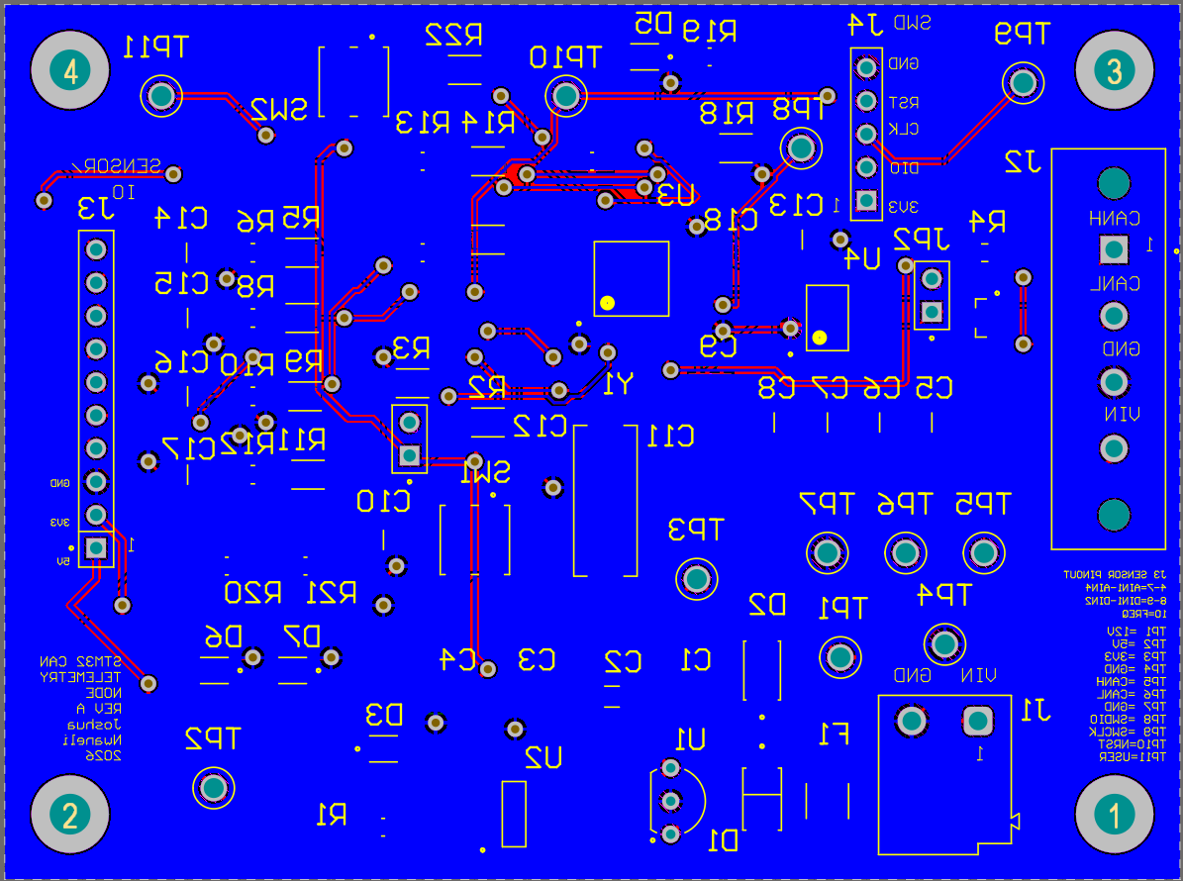
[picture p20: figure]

Figure 8: Final PCB Bottom View

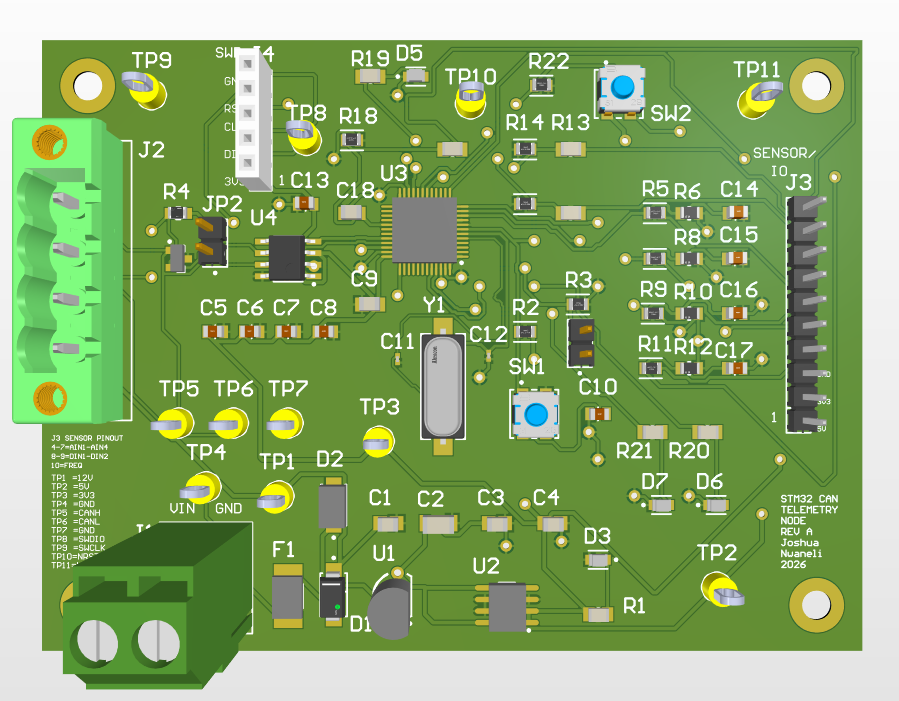
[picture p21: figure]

Figure 9: 3D Top Render


Figure 10: 3D Angled Render

# 10. Design Rule Check

Before generating manufacturing outputs, the design was run through the Altium DRC engine. The rule set covers clearance constraints, short-circuit detection, unrouted net detection, trace width rules, hole size and hole-to-hole clearance, solder mask sliver checks, net antenna checks, and height constraints. The PCB passed with 0 warnings, 0 rule violations, and 0 unrouted nets across all checked categories. Figure 11 shows the full DRC report.


Figure 11: DRC Report Showing 0 Rule Violations

# 11. Manufacturing Outputs

After the DRC passed, the following output files were generated and organized in the project output folder (Figure 12):

- Schematic PDF — complete multi-sheet schematic export (STM32_CAN_Telemetry_Node_Schematic.PDF).
- Gerber files — copper layers, silkscreen, solder mask, and board outline.
- NC Drill files — drill data for all through-hole and via passes.
- Bill of Materials — component list with designators, values, and footprints (STM32_CAN_Telemetry_Node_BOM.xlsx). Some manufacturer part numbers may be refined before fabrication.
- Pick-and-place file — centroid data for all SMD components.
- PCB 2D images — top and bottom layer exports for visual reference and fabrication verification.
- 3D renders — Altium model screenshots showing component placement and board form factor.
- DRC report — saved as a reference confirming the design passed all rule checks before output generation.

This package is intended to be sufficient for PCB fabrication, pending final part number verification on any components with placeholder references.

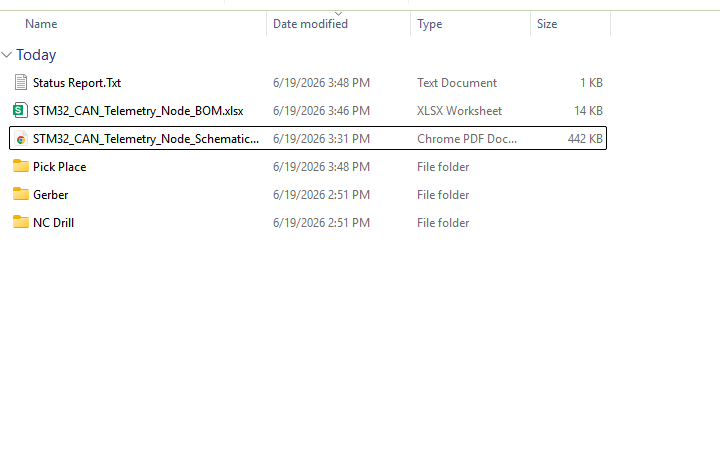
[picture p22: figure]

Figure 12: Manufacturing Outputs Folder

# 12. Bring-Up Test Plan Summary

The following bring-up sequence is planned for when the Rev A board is assembled. Steps are ordered to isolate issues at each power and logic stage before proceeding.

- Visual inspection — check for solder bridges, missing components, and correct part orientation before applying power.
- Continuity check — verify that the VIN, +5 V, and +3.3 V rails are not shorted to GND.
- Current-limited power-up — apply 12 V from a bench supply with a current limit; confirm stable draw and no overheating.
- Test point measurements — probe TP1–TP4 to confirm VIN_12V, +5 V, and +3.3 V are within expected ranges.
- Power LED check — confirm the power indicator LED illuminates when the +3.3 V rail is active.
- ST-Link connection — connect an ST-Link programmer to J4 and verify the STM32 is detectable in STM32CubeProgrammer.
- LED blink firmware — flash a GPIO toggle program to blink LED_STATUS, confirming crystal oscillation, SWD, and flash programming.
- ADC input test — apply known voltages to AIN1–AIN4 and read back ADC counts via SWD to verify resistor divider scaling.
- CAN transmission test — connect a CAN analyzer to J2 and run firmware that transmits ID 0x100 at 500 kbps; verify the frame and payload.
- LED activity check — confirm LED_CAN toggles on each CAN transmission and LED_ERROR remains off under normal operation.

# 13. Future Rev B Improvements

Rev A is intended as a layout validation and design proof. The following improvements are planned for Rev B based on design review and anticipated bring-up findings:

- Complete physical assembly and full validation of all Rev A circuits.
- Firmware development: ADC sampling, CAN frame encoding at ID 0x100, and 100 ms transmit scheduling.
- CAN analyzer testing to verify bit timing, frame structure, and message content.
- More compact PCB layout after Rev A component placement is validated.
- Improved automotive-grade protection on the analog and digital input lines.
- USB-C connector for firmware programming and debug as an alternative to the SWD header.
- Optional SD card for local data logging during vehicle testing.
- Enclosure or mounting bracket design for in-vehicle installation.
- Optional second CAN channel for expanded network connectivity.
- Final manufacturer part number selection and footprint verification for any components with placeholder references.

# 14. Conclusion

The STM32 CAN Telemetry Node Rev A is a complete hardware design covering schematic capture, power architecture, STM32 support circuitry, CAN interface design, sensor input conditioning, PCB routing, DRC verification, and manufacturing output preparation. The design was developed end-to-end in Altium Designer, from a system block diagram through to a manufacturing output package ready for review before fabrication.

The schematic is organized across six sheets, each handling a distinct subsystem. The power section uses a two-stage regulation chain with input protection for a 12 V vehicle environment. The STM32 section includes all required support components: decoupling capacitors, external crystal oscillator, and reset and boot circuitry. The CAN interface uses a 3.3 V transceiver with bus protection and optional end-of-line termination. The sensor front-end conditions seven input signals for the STM32 ADC, GPIO, and timer peripherals. Debug infrastructure — status LEDs, test points, SWD header, and user button — was included to support bring-up without requiring additional external hardware.

The PCB passed Altium DRC with 0 warnings, 0 rule violations, and 0 unrouted nets, and the full manufacturing output package has been generated. Physical assembly and firmware bring-up are planned as the next steps. This project demonstrates proficiency in schematic design, PCB layout, power architecture, embedded microcontroller support circuitry, CAN interface design, sensor signal conditioning, routing, DRC cleanup, and manufacturing output preparation.

# Appendix A: PCB Section Close-Ups

The following close-up views show individual functional zones of the PCB top copper layer for reference during bring-up and assembly review.

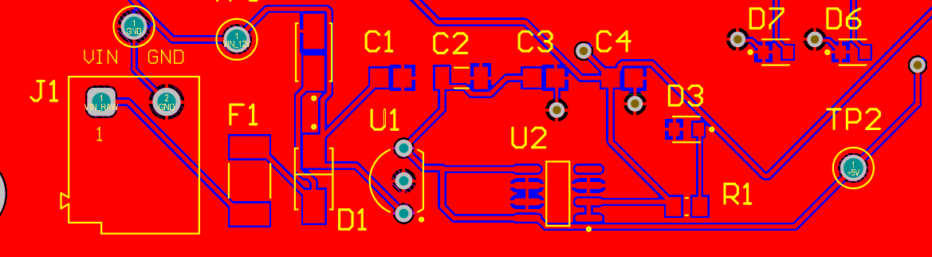
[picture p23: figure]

Figure 13: Power Section PCB Close-Up

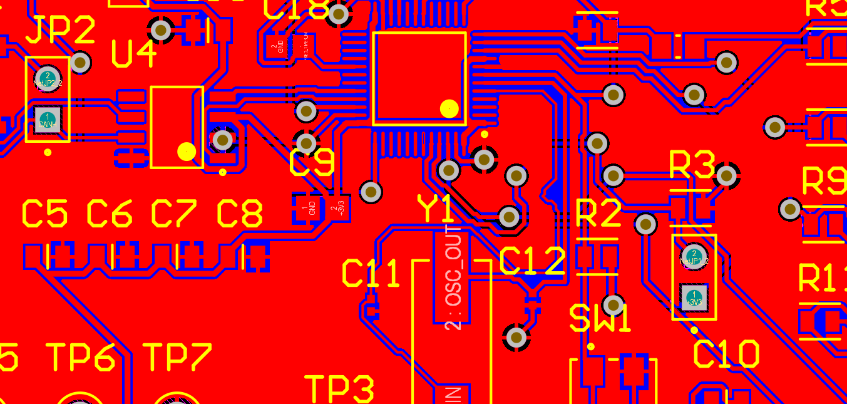
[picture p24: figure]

Figure 14: STM32 MCU Section PCB Close-Up

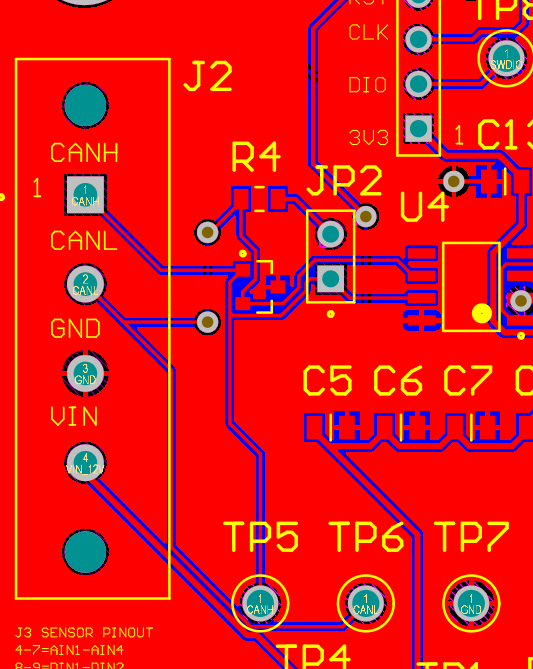
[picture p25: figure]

Figure 15: CAN Section PCB Close-Up

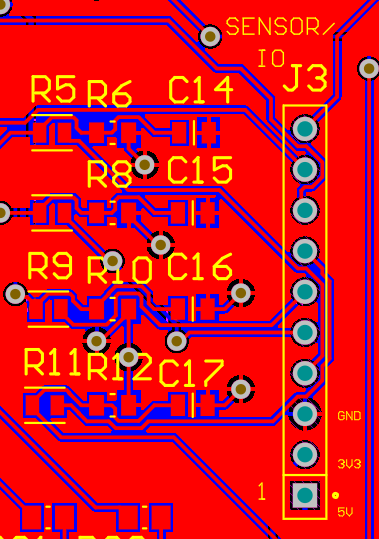
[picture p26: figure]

Figure 16: Sensor Input Section PCB Close-Up

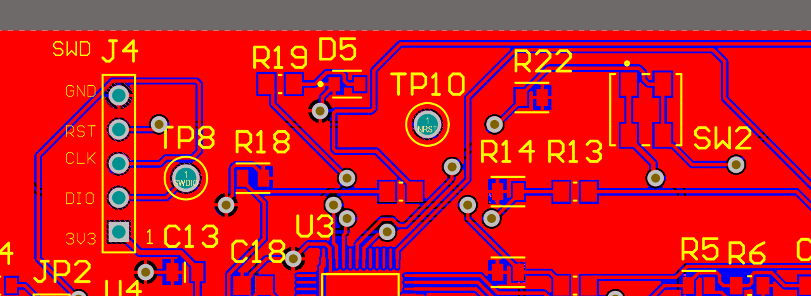
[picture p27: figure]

Figure 17: Debug and SWD Section PCB Close-Up

STM32 CAN Telemetry Node Rev A | Joshua Nwaneli | Page 1

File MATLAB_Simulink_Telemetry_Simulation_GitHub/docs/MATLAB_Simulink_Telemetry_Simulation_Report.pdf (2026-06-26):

STM32 CAN Telemetry Node Rev A - MATLAB/Simulink Telemetry Simulation | Page 1

# MATLAB/Simulink Sensor Filtering and CAN Telemetry Simulation

Supporting simulation report for STM32 CAN Telemetry Node - Rev A

## Overview

This report documents the MATLAB/Simulink telemetry simulation created to support the STM32 CAN Telemetry Node Rev A project. The simulation models four analog sensor channels, converts the signals into STM32-style ADC counts, applies filtering, and demonstrates the planned CAN payload structure for telemetry frame ID 0x100.

## Project Status

This is a simulation and documentation artifact. It does not claim physical PCB, ADC, or CAN bus validation. The Rev A PCB and starter firmware are prepared for planned hardware bring-up after board assembly.

## CAN Payload Format

CAN ID | DLC | Bytes | Signal | Description
0x100 | 8 | Byte 0-1 | AIN1_RAW | Raw ADC value from AIN1
0x100 | 8 | Byte 2-3 | AIN2_RAW | Raw ADC value from AIN2
0x100 | 8 | Byte 4-5 | AIN3_RAW | Raw ADC value from AIN3
0x100 | 8 | Byte 6-7 | AIN4_RAW | Raw ADC value from AIN4

## Signal Path

Analog sensor input -> resistor-divider scaling -> STM32 ADC count estimate -> filtering -> CAN ID 0x100 payload formatting.

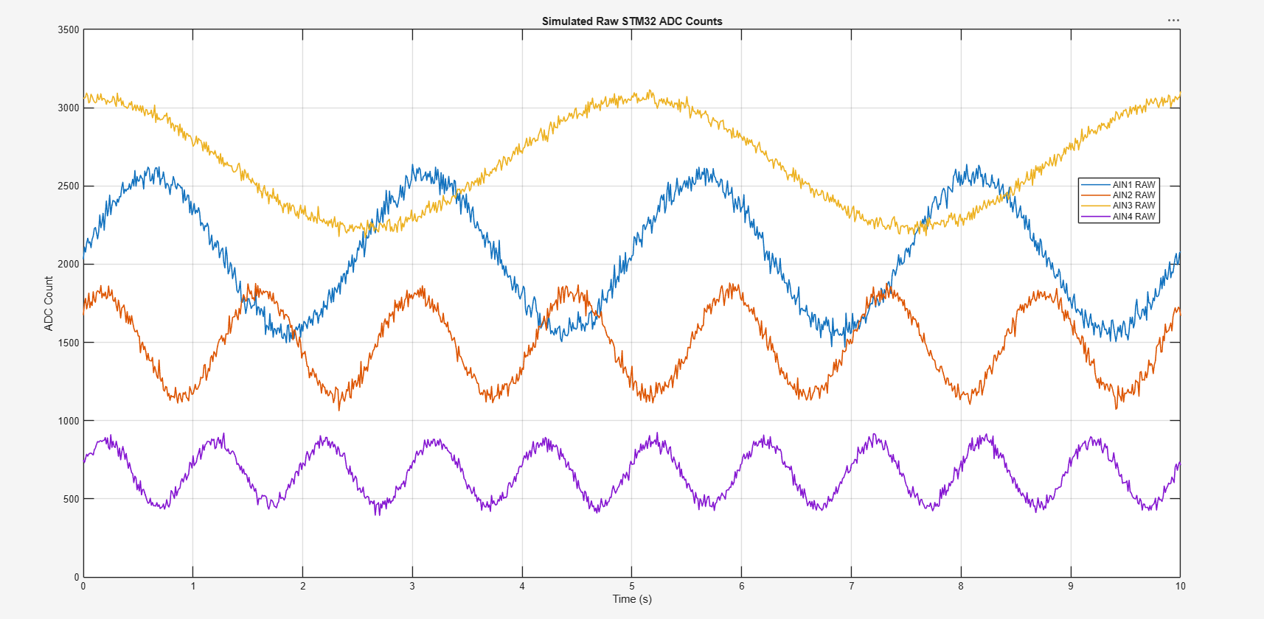
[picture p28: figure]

STM32 CAN Telemetry Node Rev A - MATLAB/Simulink Telemetry Simulation | Page 2

## MATLAB Simulation Outputs

The MATLAB simulation generates synthetic four-channel telemetry data, reconstructs sensor-side voltages from ADC counts, applies moving-average filtering, and packs the last sample into the planned CAN payload format.

Figure 1. Simulated raw STM32 ADC counts for four analog telemetry channels.

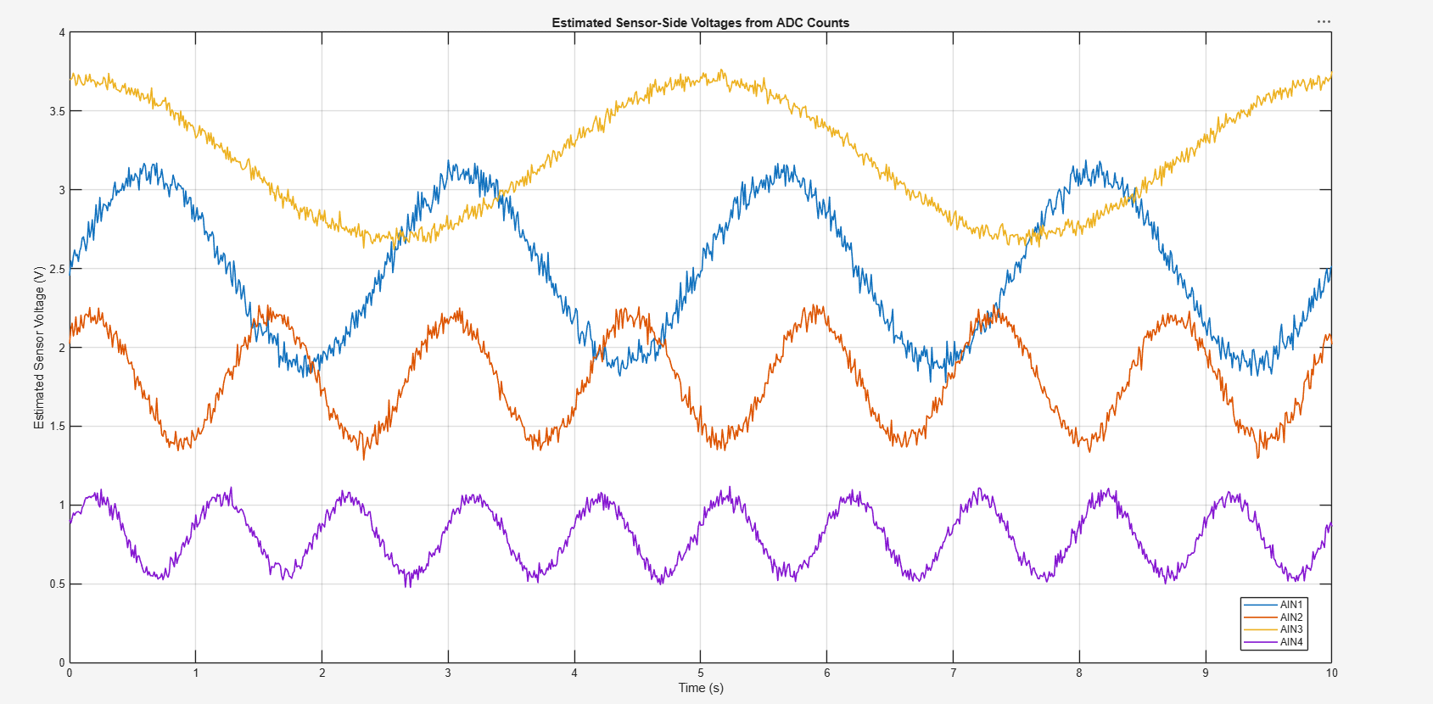
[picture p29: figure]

STM32 CAN Telemetry Node Rev A - MATLAB/Simulink Telemetry Simulation | Page 3

Figure 2. Estimated sensor-side voltages reconstructed from ADC counts using the Rev A resistor-divider model.

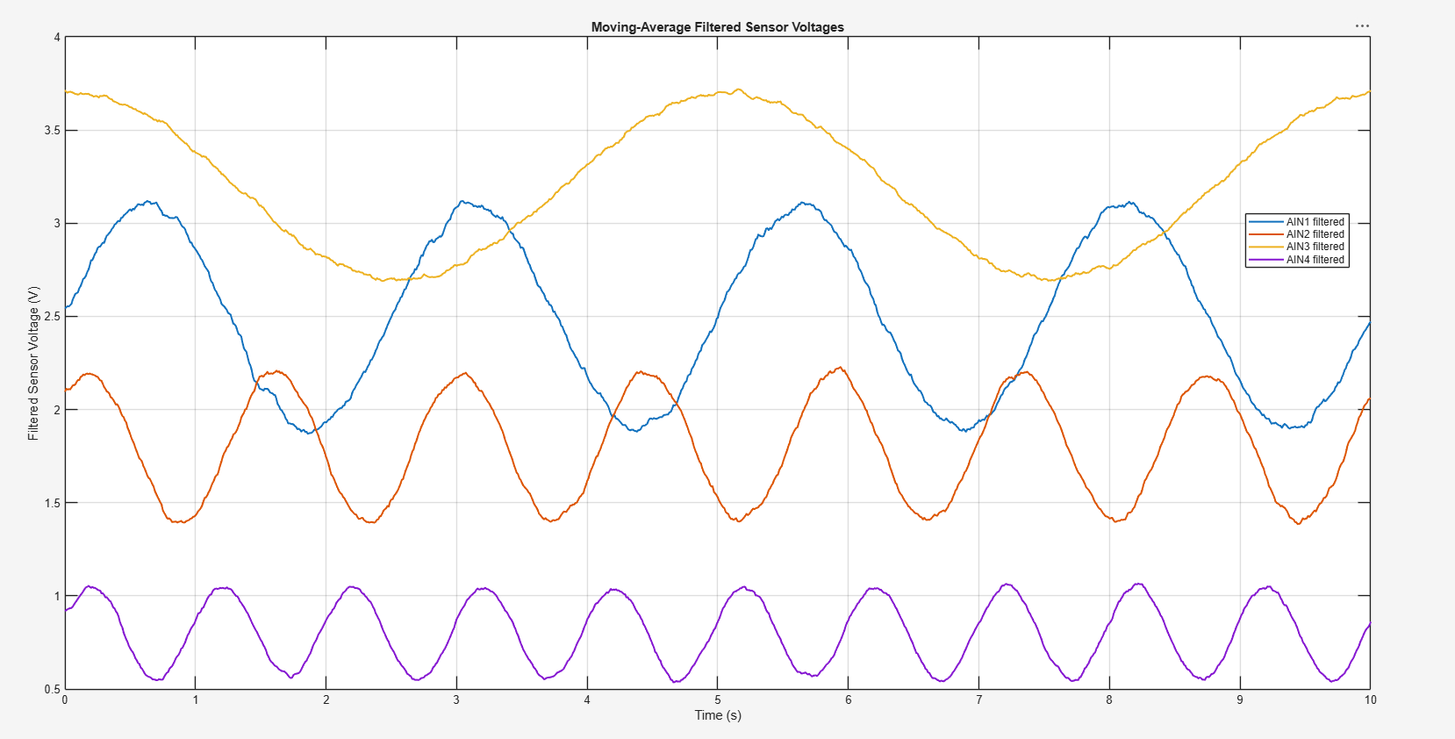
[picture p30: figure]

STM32 CAN Telemetry Node Rev A - MATLAB/Simulink Telemetry Simulation | Page 4

Figure 3. Moving-average filtered sensor voltage estimates for AIN1-AIN4.


STM32 CAN Telemetry Node Rev A - MATLAB/Simulink Telemetry Simulation | Page 5

Figure 4. Example 8-byte CAN payload for standard ID 0x100, showing little-endian packing of four raw ADC values.


STM32 CAN Telemetry Node Rev A - MATLAB/Simulink Telemetry Simulation | Page 6

## Simulink Model and Scope Outputs

The Simulink model visualizes the planned telemetry signal path for AIN1-AIN4. Each channel includes a simulated sensor input, Rev A divider scaling, ADC count conversion, and a first-order discrete low-pass filter before the filtered telemetry scope output.

Figure 5. Simulink signal-flow model showing four sensor channels, divider scaling, ADC count conversion, discrete low-pass filtering, mux blocks, and scopes.


STM32 CAN Telemetry Node Rev A - MATLAB/Simulink Telemetry Simulation | Page 7

Figure 6. Simulink raw ADC counts scope output for the four simulated telemetry channels.


STM32 CAN Telemetry Node Rev A - MATLAB/Simulink Telemetry Simulation | Page 8

Figure 7. Simulink filtered ADC counts scope output after first-order discrete low-pass filtering.

STM32 CAN Telemetry Node Rev A - MATLAB/Simulink Telemetry Simulation | Page 9

## Implementation Notes

### MATLAB script responsibilities:

- Synthetic four-channel sensor generation
- 12-bit ADC conversion using 3.3 V reference
- Rev A resistor-divider model using 10 kOhm / 20 kOhm values
- Moving-average filtering
- Little-endian packing of four 16-bit ADC values into an 8-byte CAN payload

### Simulink model responsibilities:

- Visual signal-flow model for AIN1-AIN4
- Divider scaling and ADC count conversion blocks
- First-order discrete low-pass filtering
- Raw and filtered ADC scope visualization

### Resume summary:

Developed MATLAB/Simulink telemetry simulations for the STM32 CAN node, modeling ADC scaling, sensor filtering, and CAN ID 0x100 payload formatting before hardware bring-up.

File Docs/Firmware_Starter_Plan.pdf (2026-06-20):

STM32 CAN Telemetry Node Rev A | Joshua Nwaneli | Page 1

# STM32 CAN Telemetry Node

Rev A - Firmware Starter Plan

Author | Joshua Nwaneli
Date | June 2026
Design Tool | Altium Designer
PCB | STM32 CAN Telemetry Node Rev A
MCU | STM32F103C8T6, LQFP-48
Status | Schematic complete - PCB routed - DRC clean - Bring-up planned

This document describes the planned starter firmware for the STM32 CAN Telemetry Node Rev A. The goal is to provide a clear firmware direction for board bring-up: initialize GPIO, ADC, timer input, and CAN, then transmit sensor data using a simple CAN frame. This is a firmware plan; implementation and validation are planned future steps.

## 1. Firmware Goals

- Bring up the STM32F103C8T6 on the custom PCB.
- Verify GPIO output using LED_STATUS.
- Read analog inputs AIN1-AIN4 through the ADC.
- Read digital inputs DIN1 and DIN2 through GPIO.
- Measure FREQ_IN using a timer-capable input pin.
- Transmit a CAN telemetry frame with ID 0x100 every 100 ms.
- Use LED_CAN for transmit activity and LED_ERROR for fault indication.

## 2. Development Environment

Item | Planned Choice
IDE | STM32CubeIDE
Programmer/debugger | ST-Link through J4 SWD header
MCU | STM32F103C8T6, LQFP-48
Clock source | External 8 MHz crystal planned
CAN bitrate | 500 kbps planned
Transmit period | 100 ms planned

## 3. Peripheral Plan

Peripheral | Purpose
GPIO | LEDs, user button, digital inputs, reset/debug-related signals
ADC | Read AIN1-AIN4 analog sensor channels
CAN | Transmit telemetry frame ID 0x100
Timer input | Measure FREQ_IN or wheel-speed signal
SysTick/timer delay | Schedule 100 ms transmit period
SWD | Programming and debugging through J4

## 4. Signal Assignment Summary

Signal | Firmware Role
ADC_IN0 | AIN1 raw ADC reading
ADC_IN1 | AIN2 raw ADC reading
ADC_IN2 | AIN3 raw ADC reading
ADC_IN3 | AIN4 raw ADC reading
DIGITAL_IN1 | DIN1 logic input
DIGITAL_IN2 | DIN2 logic input
FREQ_TIMER_IN | Frequency/wheel-speed timer capture input
CAN_TX/CAN_RX | CAN transceiver interface
LED_STATUS | Heartbeat/status LED
LED_CAN | Toggles on CAN transmit
LED_ERROR | Error or fault indication
USER_BUTTON | Firmware-controlled user input

## 5. Main Loop Pseudocode

while (1)
{
read_adc_channels();
read_digital_inputs();
measure_frequency_input(); pack_adc_values_into_can_frame(); send_can_message(0x100);
toggle_led_can();
update_status_led();
delay_ms(100);
}

## 6. CAN Message Format

CAN ID | DLC | Bytes | Signal | Description
0x100 | 8 | Byte 0-1 | AIN1_RAW | Raw ADC value from AIN1
0x100 | 8 | Byte 2-3 | AIN2_RAW | Raw ADC value from AIN2
0x100 | 8 | Byte 4-5 | AIN3_RAW | Raw ADC value from AIN3
0x100 | 8 | Byte 6-7 | AIN4_RAW | Raw ADC value from AIN4

## 7. Initial Firmware Milestones

1 Create STM32CubeIDE project for STM32F103C8T6.
2 Configure system clock using the external crystal.
3 Configure GPIO for LEDs and user button.
4 Flash LED blink program and verify LED_STATUS. 5 Configure ADC channels and read AIN1-AIN4.
6 Configure CAN at 500 kbps.
7 Transmit ID 0x100 every 100 ms.
8 Verify CAN frame reception using a CAN analyzer. 9 Add error handling and LED_ERROR behavior.

## 8. Future Firmware Improvements

- Convert raw ADC counts to calibrated sensor units.
- Add CAN receive support for configuration commands.
- Add diagnostic CAN messages.
- Add input fault detection for open/shorted sensors.
- Add frequency-to-speed conversion for wheel-speed input.
- Add bootloader workflow or USB-C debug/programming in a future hardware revision.
- Add SD card data logging if future hardware supports it.

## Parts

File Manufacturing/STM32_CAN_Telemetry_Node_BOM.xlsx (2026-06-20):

Name | Description | Designator | Footprint | LibRef | Quantity
10uF |  | C1, C3, C4, C9 | CAPC2013X140X50ML20T25 | CMP-2007-04702-1 | 4
22uF | CAP 22uF 10V ±20% 1206 (3216 Metric) Thickness 1.9mm SMD | C2 | CAPC1206(3216)190_N | CMP-1037-04990-1 | 1
0.1uF | CC0805KKX7RYBB104 Capacitor Ceramic 0.01uF 250V X7R 10% 0805 T/R | C5, C6, C7, C8, C10, C13, C14, C15, C16, C17 | FP-CC0805-EB-MFG | CMP-00621-107850848-1 | 10
27pF |  | C11, C12 | CAPC0603X33X15ML03T05 | CMP-2010-00173-1 | 2
1nF |  | C18 | CAPC2013X127X50NL20T25 | CMP-2007-04833-1 | 1
SS14 Schottky | DIODE SCHOTTKY 40V 1A SMA | D1 | FP-403AE-MFG | CMP-2000-04943-2 | 1
SMAJ18A TVS | Transient Voltage Suppressor, 6.40 to 231 V, 18 V Stand-off Voltage, Uni-Directional, -55 to 155 degC, 2-pin DO-214AC, Pb-Free, Tape and Reel | D2 | VISH-DO-214AC-2_M | CMP-0548-00222-2 | 1
Power LED | LED RED DIFFUSED SMD | D3 | FP-SML-LXT0805IW-TR-MFG | CMP-1724-00002-2 | 1
CAN TVS Diode | Dual-line ESD/transient protection for CANH and CANL | D4 | ONSC-SOT-23-3-318-08_V | CMP-1063-00169-1 | 1
Status LED | LED RED DIFFUSED SMD | D5 | FP-SML-LXT0805IW-TR-MFG | CMP-1724-00002-2 | 1
CAN Activity LED | LED RED DIFFUSED SMD | D6 | FP-SML-LXT0805IW-TR-MFG | CMP-1724-00002-2 | 1
Error LED | LED RED DIFFUSED SMD | D7 | FP-SML-LXT0805IW-TR-MFG | CMP-1724-00002-2 | 1
0.5A PTC Fuse | PTC Resettable Fuse, 0.8 W, 30 V, -40 to 85 degC, 2-Pin SMD, RoHS, Tape and Reel | F1 | LFUS-1812L05030PR_V | CMP-2000-05508-1 | 1
12V_INPUT | Terminal Block, 5.08MM Pitch, Double Level Horizontal, 12-30 AWG, 2 Pin | J1 | 691249510002 | CMP-03913-78871301-2 | 1
CAN Connector | TERM BLOCK HDR 4POS VERT 5.08MM | J2 | FP-1777099-MFG | CMP-09399-000012-1 | 1
Sensor Header | TSW-110-07-T-S TSW - Samtec 2.54mm Pin Header 10.92mm Overall Pin Length (07) (mcv)(TO22) | J3 | FP-TSW-110-07-T-S-MFG | CMP-00575-00272505-1 | 1
SWD Header | SQ Post Socket, Through-hole, Vertical, -55 to 105 degC, 2.54mm Pitch, 5-Pin, Female, RoHS | J4 | SMTC-SSW-105-01-X-S | CMP-1023-00345-1 | 1
BOOT0 Jumper | CONN HEADER VERT 2POS 2.54MM | JP1 | FP-TSW-102-12-T-S-MFG | CMP-02766-001444-1 | 1
CAN TERM ENABLE | Jumper to enable optional 120R CAN bus termination | JP2 | FP-TSW-102-12-T-S-MFG | CMP-02766-001444-1 | 1
1K |  | R1, R13, R15, R17, R19, R20, R21 | RESC2013X50X30ML20T20 | CMP-2001-04268-1 | 7
10K | CRGP 0805 10K 1% | R2, R3, R5, R7, R9, R11, R14, R16, R18, R22 | FP-CRGP0805-IPC_C | CMP-03211-006861-1 | 10
120 | RES SMD 120 OHM 0.5% 1/8W 0805 | R4 | FP-RT0805-MFG | CMP-03412-026588-1 | 1
20K | SMD Chip Resistor, Thin Film, 20KΩ, 100 V, 0805 [2012 Metric], 100 mW, 0.1%, RN73 Series | R6, R8, R10, R12 | FP-RN732A-MFG | CMP-03211-001671-1 | 4
RESET | Normally open reset pushbutton for STM32 NRST | SW1 | FP-7914J-1-032-MFG | CMP-07427-000007-1 | 1
USER BUTTON | Normally open user pushbutton input | SW2 | FP-7914J-1-032-MFG | CMP-07427-000007-1 | 1
12V | 12V Test Point | TP1 | KSTN-5014_V | CMP-1672-00006-4 | 1
5V | 5V Test Point | TP2 | KSTN-5014_V | CMP-1672-00006-4 | 1
3.3V | 3.3V Test Point | TP3 | KSTN-5014_V | CMP-1672-00006-4 | 1
GND | Ground Test Point | TP4 | KSTN-5014_V | CMP-1672-00006-4 | 1
CANH Test Point | Test Point, Yellow, Through Hole, RoHS, Bulk | TP5 | KSTN-5014_V | CMP-1672-00006-4 | 1
CANL Test Point | Test Point, Yellow, Through Hole, RoHS, Bulk | TP6 | KSTN-5014_V | CMP-1672-00006-4 | 1
GND Test Point | Test Point, Yellow, Through Hole, RoHS, Bulk | TP7 | KSTN-5014_V | CMP-1672-00006-4 | 1
SWDIO Test Point | Test Point, Yellow, Through Hole, RoHS, Bulk | TP8 | KSTN-5014_V | CMP-1672-00006-4 | 1
SWCLK Test Point | Test Point, Yellow, Through Hole, RoHS, Bulk | TP9 | KSTN-5014_V | CMP-1672-00006-4 | 1
NRST Test Point | Test Point, Yellow, Through Hole, RoHS, Bulk | TP10 | KSTN-5014_V | CMP-1672-00006-4 | 1
USER_BUTTON Test Point | Test Point, Yellow, Through Hole, RoHS, Bulk | TP11 | KSTN-5014_V | CMP-1672-00006-4 | 1
5V Regulator | Regulates protected 12V input down to 5V | U1 | LP3 | CMP-0324-00078-1 | 1
3.3V LDO | 500 mA, Low Noise, LDO Micropower Regulator, 1.8 to 20 V Vin, 3.3 V Vout, 8-pin SOIC (S8-8), -40 to 125 degC, Pb-Free | U2 | LT-S8-8_N | CMP-0476-01566-1 | 1
STM32F103C8T6 | ARM Cortex-M3 32-bit MCU, 64 KB Flash, 20 KB Internal RAM, 37 I/Os, 48-pin LQFP, -40 to 85 degC, Tray | U3 | STM-LQFP48_L | CMP-0237-00215-3 | 1
CAN Transceiver | CAN Bus Transceiver, 3.3 V, -40 to 85 degC, 8-Pin SOIC (D), Green (RoHS & no Sb/Br), Tube | U4 | D0008A_M | CMP-0315-00046-3 | 1
8MHz Crystal | CRYSTAL 8.0000MHZ 18PF SMD | Y1 | FP-ABLS-MFG | CMP-27762-009874-1 | 1

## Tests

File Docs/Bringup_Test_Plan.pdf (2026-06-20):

STM32 CAN Telemetry Node Rev A | Joshua Nwaneli | Page 1

# STM32 CAN Telemetry Node

## Rev A - Bring-Up Test Plan

Author | Joshua Nwaneli
Date | June 2026
Design Tool | Altium Designer
PCB | STM32 CAN Telemetry Node Rev A
MCU | STM32F103C8T6, LQFP-48
Status | Schematic complete - PCB routed - DRC clean - Bring-up planned

This document defines the planned bring-up sequence for the STM32 CAN Telemetry Node Rev A after PCB assembly. The goal is to validate power, programming, sensor inputs, and CAN communication in a controlled order. This is a planned test procedure; physical board validation has not been completed yet.

# 1. Required Equipment

### - Current-limited bench power supply

### - Digital multimeter

### - Oscilloscope if available

### - ST-Link programmer/debugger

### - STM32CubeProgrammer and STM32CubeIDE

### - CAN analyzer or USB-to-CAN adapter

### - Jumper wires and test leads

### - Known voltage source or potentiometer for ADC testing

### - 120 ohm CAN termination if needed

# 2. Pre-Power Visual Inspection

Check | Pass/Fail | Notes

Inspect PCB for solder bridges or visible damage

Verify diode and LED orientation

Verify STM32 pin 1 orientation

Verify CAN transceiver orientation

Verify regulator orientation and solder joints

Confirm connector labels match schematic intent

Inspect mounting holes and board edges

# 3. Continuity Checks - Board Unpowered

Before applying power, use a multimeter to confirm that the major rails are not shorted to ground.

Measurement | Expected Result | Pass/Fail
VIN_12V to GND | No direct short
+5V to GND | No direct short
+3V3 to GND | No direct short
TP4 and TP7 to GND | Continuity to ground

# 4. First Power-Up

1 Set bench supply to 12 V.
2 Set current limit to a conservative value such as 100-200 mA for first power-up.
3 Connect supply to J1 with correct polarity.
4 Turn on supply and watch current draw.
5 Turn off immediately if current draw is unexpectedly high, any component heats quickly, or visible damage appears.
Item | Expected Result | Pass/Fail
Input current | Stable and below current limit
Power LED D3 | On when +3.3 V is active
Regulators | No overheating
Board behavior | No smoke, smell, or visible damage

# 5. Power Rail Measurements

Test Point | Rail | Expected Measurement | Pass/Fail
TP1 | VIN_12V | Approximately input voltage
TP2 | +5V | Approximately 5.0 V
TP3 | +3V3 | Approximately 3.3 V
TP4 | GND | Ground reference

# 6. STM32 Programming Test

1 Connect ST-Link to J4: +3.3 V, SWDIO, SWCLK, NRST, and GND. 2 Open STM32CubeProgrammer.
3 Attempt to detect the STM32 device.
4 If detected, flash a basic LED blink program.

5 Confirm LED_STATUS toggles.

Test | Expected Result | Pass/Fail
ST-Link connection | STM32 detected
Flash programming | Program downloads successfully
LED_STATUS | Blinks under firmware control

# 7. Reset and BOOT0 Test

Test | Procedure | Expected Result | Pass/Fail
Reset | Press SW1 | MCU resets and firmware restarts
BOOT0 normal mode | JP1 open/normal setting | MCU boots from flash
BOOT0 bootloader modeInstall JP1 if needed | | MCU can enter system bootloader

# 8. CAN Interface Test

1 Connect a CAN analyzer or USB-to-CAN adapter to J2.
2 Use 120 ohm termination only if the board is at the end of the CAN bus. 3 Flash firmware that transmits CAN ID 0x100 at 500 kbps every 100 ms. 4 Observe CAN frames on the analyzer.
5 Check CANH and CANL with an oscilloscope if available.
Test | Expected Result | Pass/Fail
CAN frame reception | Analyzer receives standard ID 0x100
DLC | 8 bytes
Payload | Contains AIN1-AIN4 raw ADC values
LED_CAN | Toggles on transmit
Bus health | No repeated bus-off or error states

# 9. Sensor Input Test

Input | Procedure | Expected Result | Pass/Fail
AIN1-AIN4 | Apply known voltages through safe test source | ADC counts change consistently with voltage divider scaling
DIN1-DIN2 | Toggle input between low and valid logic high | GPIO state changes correctly
FREQ_IN | Apply square wave test signal | Timer input detects frequency

# 10. Final System Acceptance Checklist

Acceptance Item | Pass/Fail | Notes

Board powers from 12 V input without abnormal current draw

+5 V and +3.3 V rails measure correctly

STM32 programs over SWD

Status LED operates under firmware control

AIN1-AIN4 read expected ADC values

DIN1-DIN2 logic states read correctly

FREQ_IN timer capture works

CAN ID 0x100 transmits at 500 kbps

CAN analyzer receives expected payload

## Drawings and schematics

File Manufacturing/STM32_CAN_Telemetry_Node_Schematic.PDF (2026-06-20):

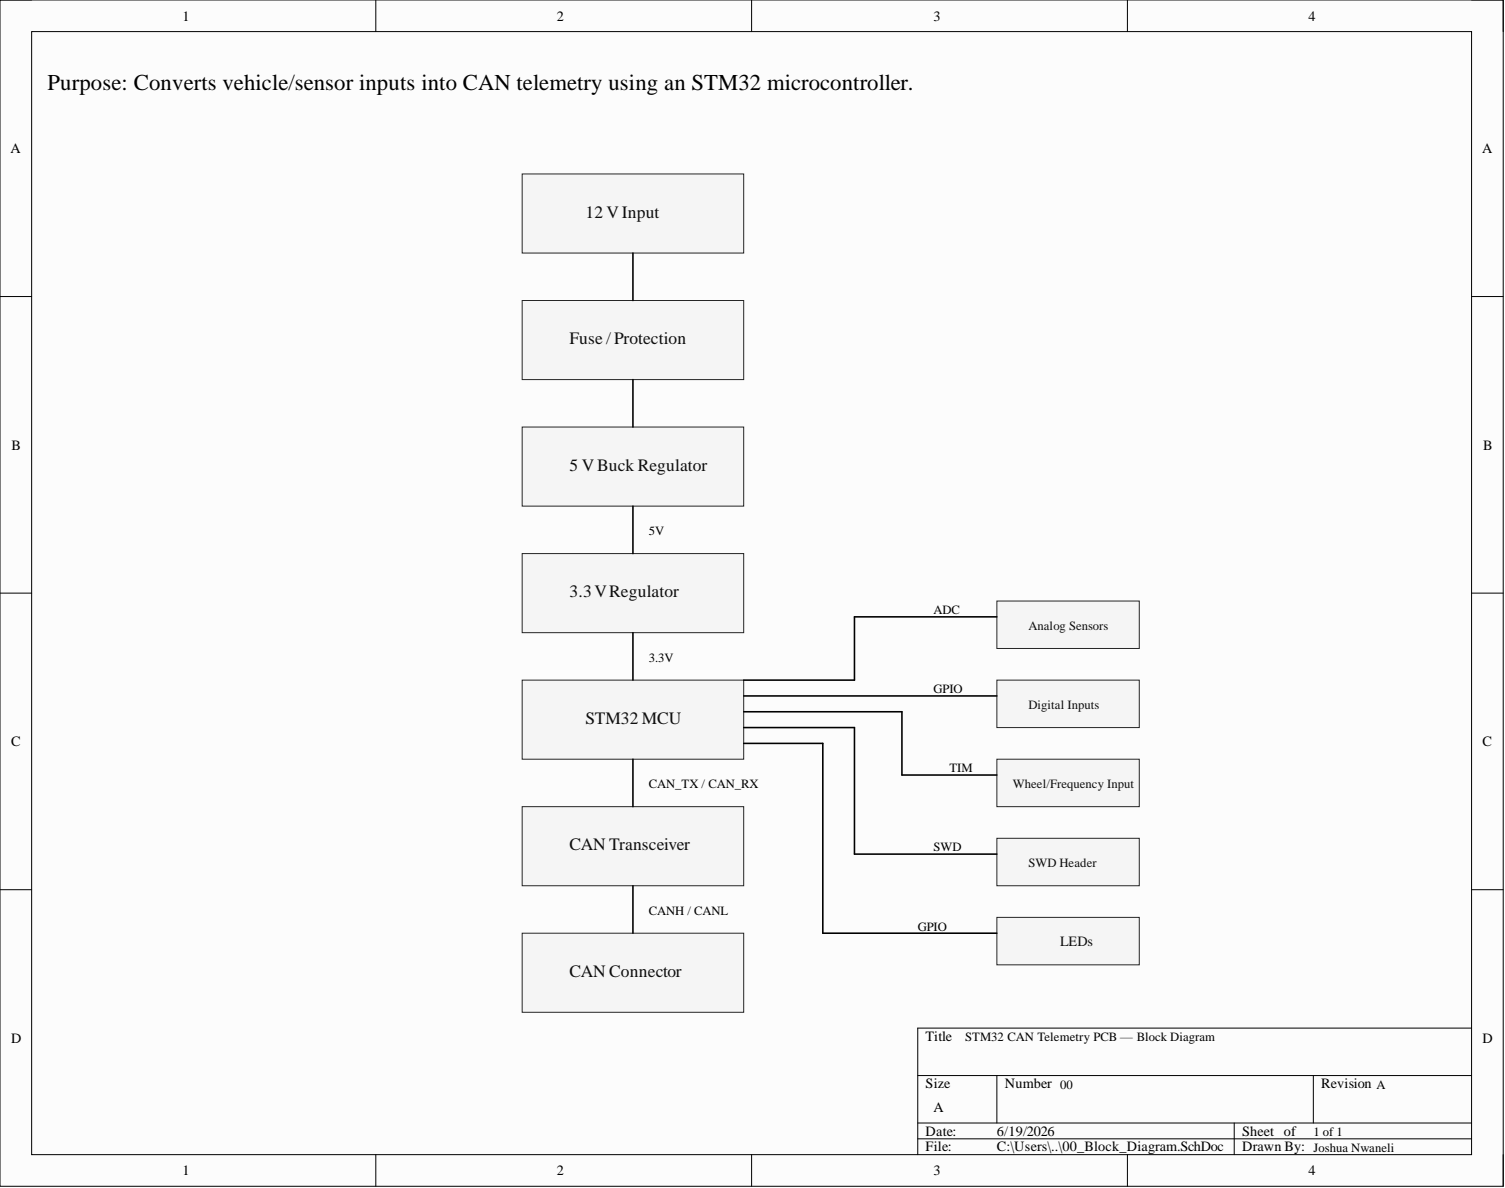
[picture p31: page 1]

Purpose: Converts vehicle/sensor inputs into CAN telemetry using an STM32 microcontroller.

STM32 CAN Telemetry PCB — Block Diagram

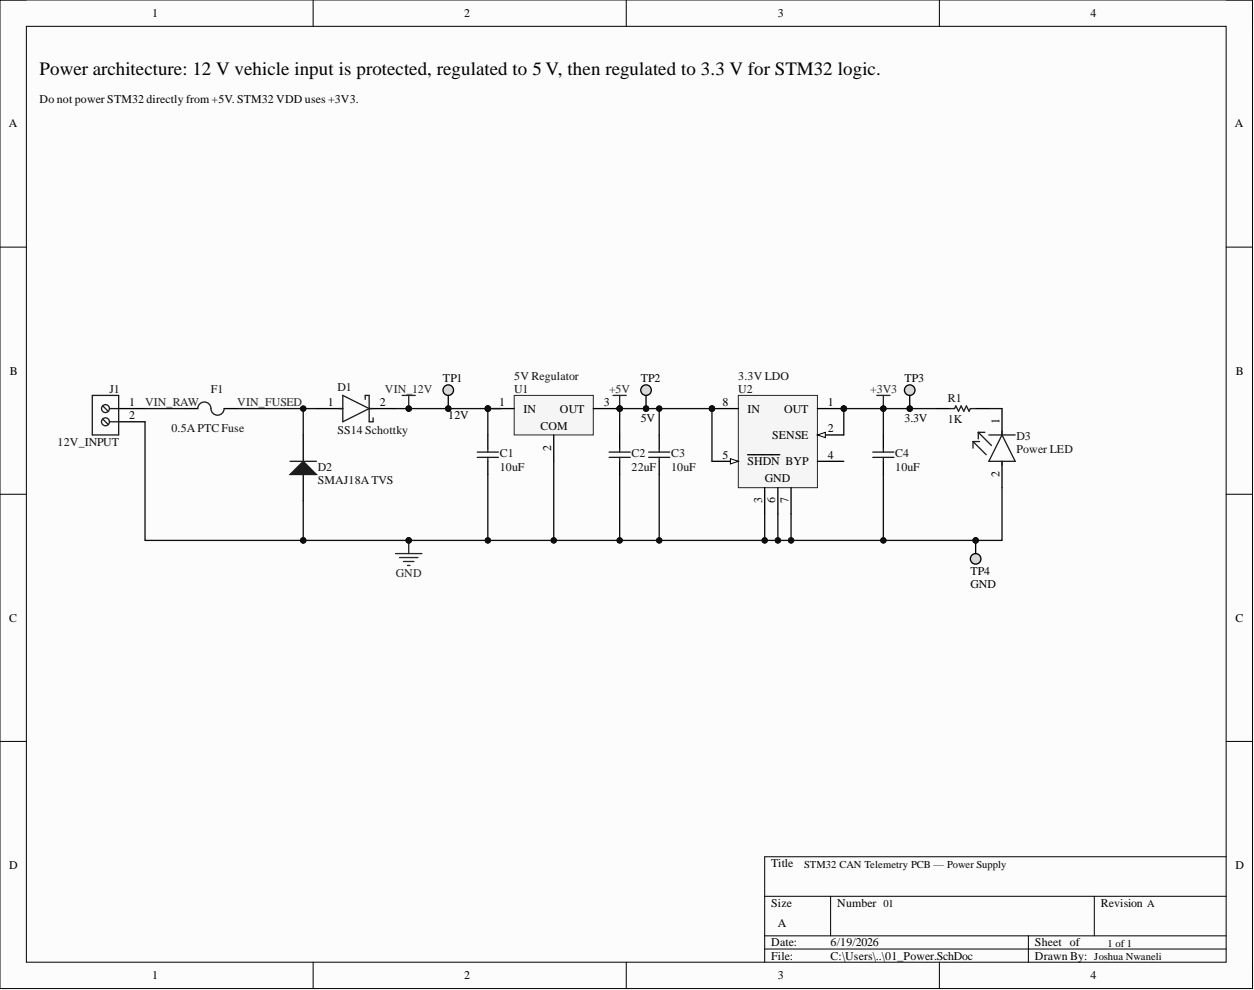
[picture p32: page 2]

ut is protected, reg

ulated to 5 V, then reg

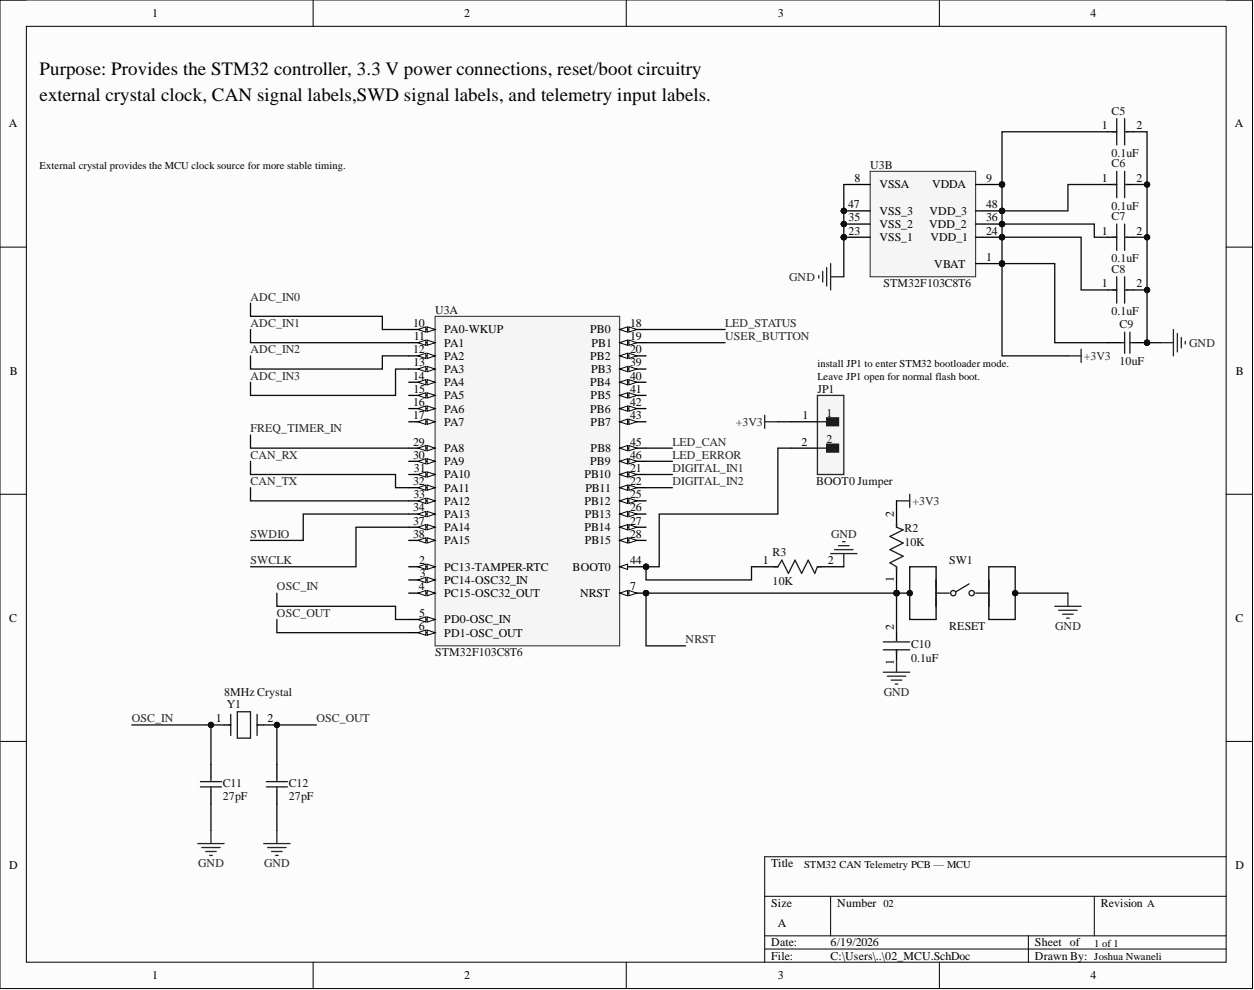
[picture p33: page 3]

Purp
external crystal clock, CAN sig

nal labels,SWD sig

4 7 | | 4 8
3 5 | | 3 6
2 3 | | 2 4 | 1

SWCL K | 2 | 4 4

OSC_ O U T | 5

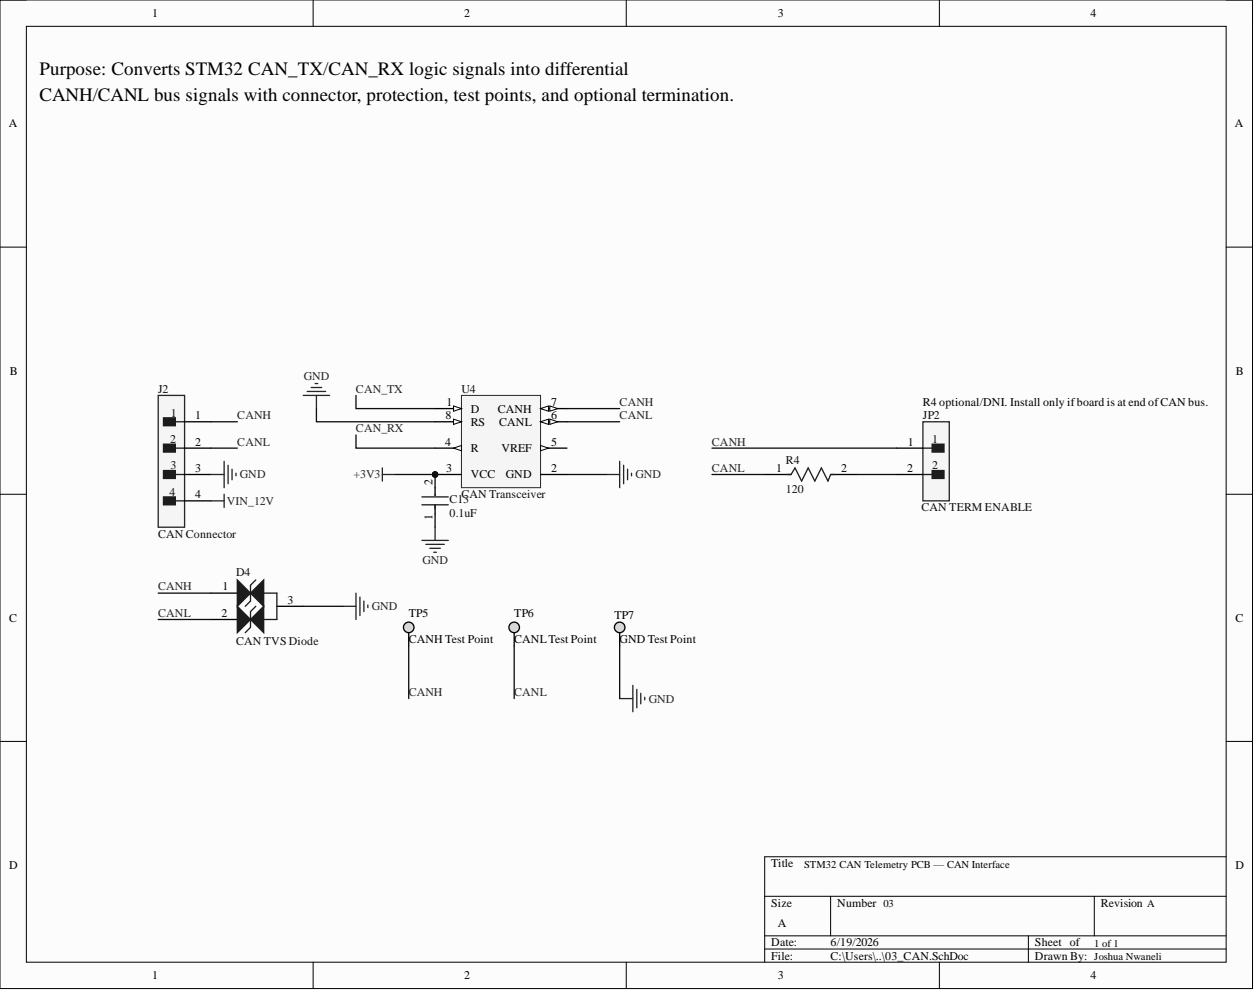
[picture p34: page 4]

Purpose: Converts STM32 CAN_TX/CAN_RX logic signals into differential
CANH/CANL bus signals with connector, protection, test points, and optional termination.

R4 optional/DNI. Install only if board is at end of CAN bus.

STM32 CAN Telemetry PCB — CAN Interface

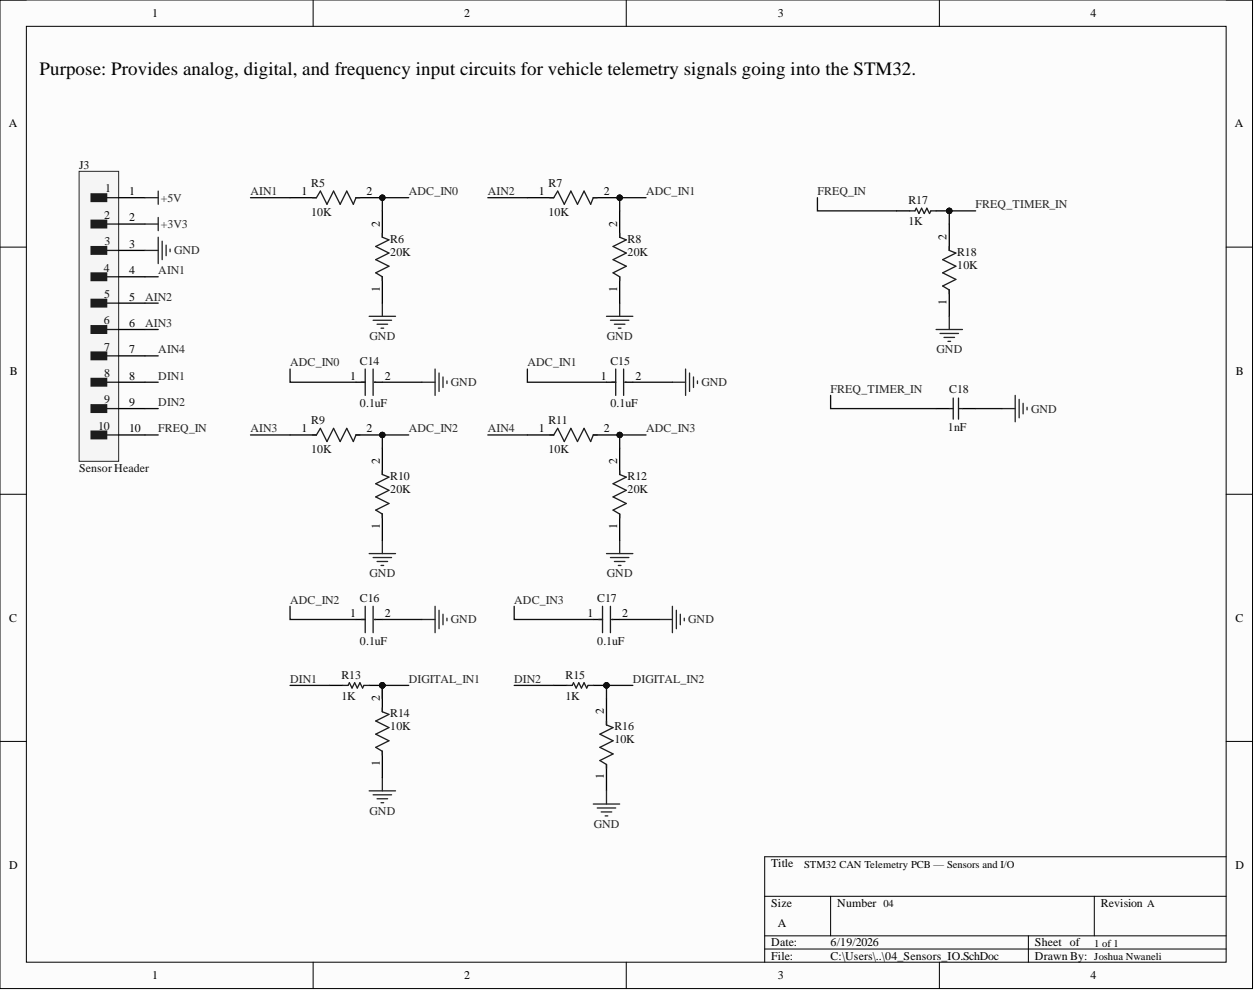
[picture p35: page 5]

Purpose: Provides analog, digital, and frequency input circuits for vehicle telemetry signals going into the STM32.

STM32 CAN Telemetry PCB — Sensors and I/O

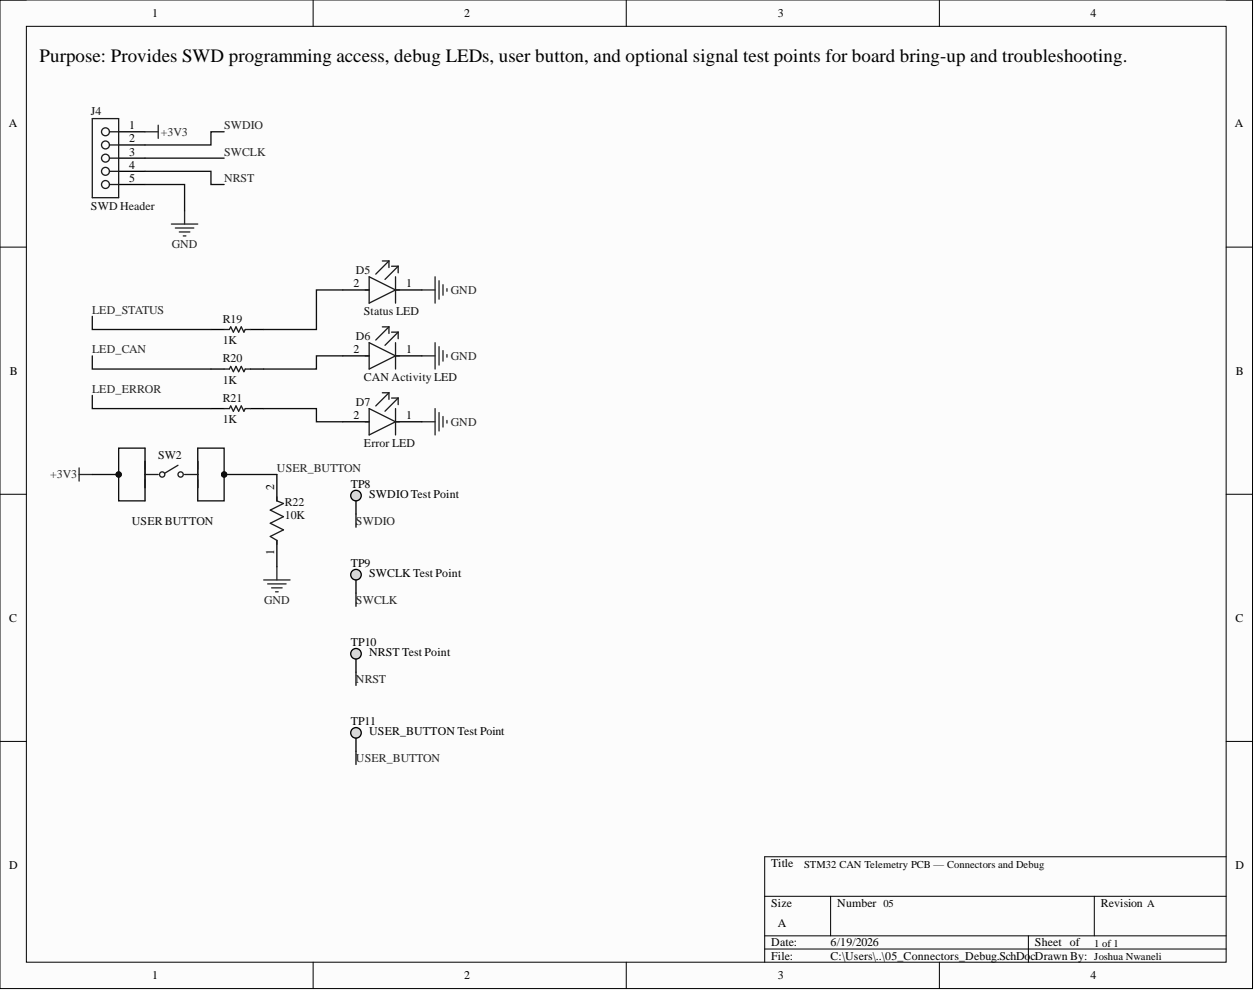
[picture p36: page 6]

Purpose: Provides SWD programming access, debug LEDs, user button, and optional signal test points for board bring-up and troubleshooting.

STM32 CAN Telemetry PCB — Connectors and Debug

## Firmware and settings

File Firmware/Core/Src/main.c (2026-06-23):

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

/* Includes ------------------------------------------------------------------*/
#include "main.h"
#include "adc.h"
#include "can.h"
#include "gpio.h"

/* USER CODE BEGIN PD */

#define CAN_TELEMETRY_ID        0x100U
#define CAN_TELEMETRY_DLC       8U
#define TELEMETRY_PERIOD_MS     100U

/* USER CODE END PD */


/* USER CODE BEGIN PV */

/*
 * Raw ADC values:
 * adc_values[0] = AIN1_RAW from PA0 / ADC_IN0
 * adc_values[1] = AIN2_RAW from PA1 / ADC_IN1
 * adc_values[2] = AIN3_RAW from PA2 / ADC_IN2
 * adc_values[3] = AIN4_RAW from PA3 / ADC_IN3
 */
uint16_t adc_values[4] = {0};

/*
 * CAN transmit objects for the planned telemetry frame.
 */
CAN_TxHeaderTypeDef TxHeader;
uint8_t TxData[8] = {0};
uint32_t TxMailbox;

/* USER CODE END PV */

void SystemClock_Config(void);

/* USER CODE BEGIN PFP */

static void Read_ADC_Channels(void);
static void Pack_CAN_Data(void);
static void Init_CAN_Message(void);

/* USER CODE END PFP */

/* USER CODE BEGIN 0 */

/*
 * Read_ADC_Channels
 *
 * Reads four ADC channels configured in ADC1 scan mode:
 * Rank 1: PA0 / ADC_IN0 / AIN1
 * Rank 2: PA1 / ADC_IN1 / AIN2
 * Rank 3: PA2 / ADC_IN2 / AIN3
 * Rank 4: PA3 / ADC_IN3 / AIN4
 *
 * Important:
 * ADC is started once, then each ranked conversion is read in order.
 * This avoids restarting the ADC sequence at Rank 1 every time.
 */
static void Read_ADC_Channels(void)
{
    HAL_ADC_Start(&hadc1);

    for (uint8_t i = 0; i < 4; i++)
    {
        if (HAL_ADC_PollForConversion(&hadc1, 10) == HAL_OK)
        {
            adc_values[i] = (uint16_t)HAL_ADC_GetValue(&hadc1);
        }
    }

    HAL_ADC_Stop(&hadc1);
}

/*
 * Pack_CAN_Data
 *
 * Packs four 16-bit raw ADC values into an 8-byte CAN payload.
 *
 * Payload format:
 * Byte 0-1: AIN1_RAW
 * Byte 2-3: AIN2_RAW
 * Byte 4-5: AIN3_RAW
 * Byte 6-7: AIN4_RAW
 *
 * Each uint16_t value is packed little-endian:
 * low byte first, high byte second.
 */
static void Pack_CAN_Data(void)
{
    TxData[0] = (uint8_t)(adc_values[0] & 0xFF);
    TxData[1] = (uint8_t)((adc_values[0] >> 8) & 0xFF);

    TxData[2] = (uint8_t)(adc_values[1] & 0xFF);
    TxData[3] = (uint8_t)((adc_values[1] >> 8) & 0xFF);

    TxData[4] = (uint8_t)(adc_values[2] & 0xFF);
    TxData[5] = (uint8_t)((adc_values[2] >> 8) & 0xFF);

    TxData[6] = (uint8_t)(adc_values[3] & 0xFF);
    TxData[7] = (uint8_t)((adc_values[3] >> 8) & 0xFF);
}

/*
 * Init_CAN_Message
 *
 * Configures the transmit header for the planned telemetry frame.
 *
 * CAN frame:
 * Standard 11-bit ID: 0x100
 * DLC: 8 bytes
 * Frame type: Data frame
 */
static void Init_CAN_Message(void)
{
    TxHeader.StdId = CAN_TELEMETRY_ID;
    TxHeader.ExtId = 0x000;
    TxHeader.IDE = CAN_ID_STD;
    TxHeader.RTR = CAN_RTR_DATA;
    TxHeader.DLC = CAN_TELEMETRY_DLC;
    TxHeader.TransmitGlobalTime = DISABLE;
}

/* USER CODE END 0 */

/**
  * @brief  The application entry point.
  * @retval int
  */
int main(void)
{
  /* MCU Configuration--------------------------------------------------------*/

  /*
   * Reset of all peripherals, initializes the Flash interface,
   * and initializes the SysTick timer.
   */
  HAL_Init();

  /*
   * Configure the system clock.
   * Current setup uses the external 8 MHz HSE crystal and PLL x9
   * for 72 MHz SYSCLK.
   */
  SystemClock_Config();

  /*
   * Initialize all configured peripherals generated by STM32CubeMX.
   */
  MX_GPIO_Init();
  MX_ADC1_Init();
  MX_CAN_Init();

  /* USER CODE BEGIN 2 */

  /*
   * Initialize debug LEDs to a known OFF state.
   * Exact LED behavior will be verified during physical board bring-up.
   */
  HAL_GPIO_WritePin(LED_STATUS_GPIO_Port, LED_STATUS_Pin, GPIO_PIN_RESET);
  HAL_GPIO_WritePin(LED_CAN_GPIO_Port, LED_CAN_Pin, GPIO_PIN_RESET);
  HAL_GPIO_WritePin(LED_ERROR_GPIO_Port, LED_ERROR_Pin, GPIO_PIN_RESET);

  /*
   * Calibrate ADC1 before first conversion.
   * This is recommended for STM32F1 ADC accuracy.
   */
  if (HAL_ADCEx_Calibration_Start(&hadc1) != HAL_OK)
  {
      HAL_GPIO_WritePin(LED_ERROR_GPIO_Port, LED_ERROR_Pin, GPIO_PIN_SET);
  }

  /*
   * Prepare and start CAN peripheral.
   * If CAN start fails, LED_ERROR is set and remains set.
   */
  Init_CAN_Message();

  if (HAL_CAN_Start(&hcan) != HAL_OK)
  {
      HAL_GPIO_WritePin(LED_ERROR_GPIO_Port, LED_ERROR_Pin, GPIO_PIN_SET);
  }

  /* USER CODE END 2 */

  /* Infinite loop */
  /* USER CODE BEGIN WHILE */
  while (1)
  {
      /*
       * Starter telemetry loop:
       * 1. Read four raw ADC channels.
       * 2. Pack values into CAN payload.
       * 3. Transmit CAN frame ID 0x100.
       * 4. Toggle LEDs for planned bring-up feedback.
       *
       * Note:
       * This loop has not been tested on Rev A hardware yet.
       */
      Read_ADC_Channels();
      Pack_CAN_Data();

      if (HAL_CAN_AddTxMessage(&hcan, &TxHeader, TxData, &TxMailbox) == HAL_OK)
      {
          /*
           * Planned behavior:
           * LED_CAN toggles whenever a CAN message is queued successfully.
           */
          HAL_GPIO_TogglePin(LED_CAN_GPIO_Port, LED_CAN_Pin);
      }
      else
      {
          /*
           * Planned behavior:
           * LED_ERROR turns on if CAN transmit queueing fails.
           */
          HAL_GPIO_WritePin(LED_ERROR_GPIO_Port, LED_ERROR_Pin, GPIO_PIN_SET);
      }

      /*
       * Planned firmware heartbeat.
       */
      HAL_GPIO_TogglePin(LED_STATUS_GPIO_Port, LED_STATUS_Pin);

      /*
       * Planned transmit period: 100 ms.
       */
      HAL_Delay(TELEMETRY_PERIOD_MS);

    /* USER CODE END WHILE */

    /* USER CODE BEGIN 3 */
  }
  /* USER CODE END 3 */
}

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


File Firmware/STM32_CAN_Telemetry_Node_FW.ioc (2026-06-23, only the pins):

Mcu.UserName=STM32F103C8Tx
PA0-WKUP.Signal=ADCx_IN0
PA1.Signal=ADCx_IN1
PA11.Signal=CAN_RX
PA12.Signal=CAN_TX
PA13.Signal=SYS_JTMS-SWDIO
PA14.Signal=SYS_JTCK-SWCLK
PA2.Signal=ADCx_IN2
PA3.Signal=ADCx_IN3
PA8.Signal=S_TIM1_CH1
PB0.GPIO_Label=LED_STATUS
PB0.Signal=GPIO_Output
PB1.GPIO_Label=USER_BUTTON
PB1.Signal=GPIO_Input
PB10.GPIO_Label=DIGITAL_IN1
PB10.Signal=GPIO_Input
PB11.GPIO_Label=DIGITAL_IN2
PB11.Signal=GPIO_Input
PB8.GPIO_Label=LED_CAN
PB8.Signal=GPIO_Output
PB9.GPIO_Label=LED_ERROR
PB9.Signal=GPIO_Output
PD0-OSC_IN.Signal=RCC_OSC_IN
PD1-OSC_OUT.Signal=RCC_OSC_OUT

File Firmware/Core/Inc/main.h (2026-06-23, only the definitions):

#define LED_STATUS_Pin GPIO_PIN_0
#define LED_STATUS_GPIO_Port GPIOB
#define USER_BUTTON_Pin GPIO_PIN_1
#define USER_BUTTON_GPIO_Port GPIOB
#define DIGITAL_IN1_Pin GPIO_PIN_10
#define DIGITAL_IN1_GPIO_Port GPIOB
#define DIGITAL_IN2_Pin GPIO_PIN_11
#define DIGITAL_IN2_GPIO_Port GPIOB
#define LED_CAN_Pin GPIO_PIN_8
#define LED_CAN_GPIO_Port GPIOB
#define LED_ERROR_Pin GPIO_PIN_9
#define LED_ERROR_GPIO_Port GPIOB

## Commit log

2026-06-23 Enhance README with figure captions
    Added figure captions for PCB and STM32CubeMX images.
2026-06-23 Add project configuration for STM32 CAN Telemetry Node
2026-07-08 Polish STM32 CAN README presentation
2026-10-09 Add WindBorne PCB submission documentation
    Added detailed documentation for the WindBorne Electrical Engineer Intern PCB submission, including project overview, design features, and images.

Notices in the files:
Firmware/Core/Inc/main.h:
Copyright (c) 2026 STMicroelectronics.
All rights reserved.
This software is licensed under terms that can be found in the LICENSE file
